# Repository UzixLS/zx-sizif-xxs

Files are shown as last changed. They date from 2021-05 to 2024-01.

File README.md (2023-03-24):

## Sizif-XXS
Smallest FPGA-based ZX Spectrum clone with real Z80.

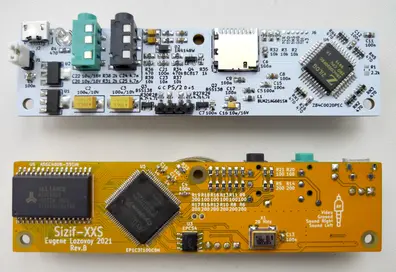
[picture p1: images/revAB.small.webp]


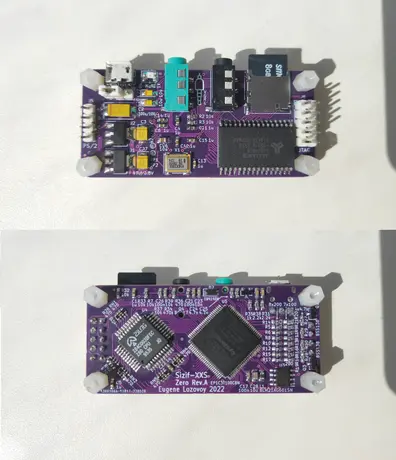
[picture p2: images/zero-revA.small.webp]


### Tech specs
* Two PCB varians: 100x24.5mm (main version) and 65x30mm (Zero version) - both are functionally identical, differs only in size
* PS/2 keyboard
* Pentagon, Spectrum 128, Spectrum 48 and Spectrum +3e modes
* Altera EP1C3T100 FPGA
* Real Z80 with 3.5MHz, 4.4MHz, 5.2MHz, 7MHz (no-wait turbo) and 14MHz (turbo with wait-states) modes
* 512K RAM
* TurboSound with switchable stereo ABC/ACB/mono output
* Integrated DivMMC and Z-Controller, 1x microSD socket
* PAL video output (AV cable like in Raspberry Pi)
* ULAplus
* SpecDrum
* Covox (Pentagon standard - port #FD)
* SounDrive (4-channel stereo covox - ports #0F, #1F, #4F, #5F)
* Tape input via 3.5" jack
* USB 5V power supply

### Magic button
Sizif has a number of configurable parameters that you can change on the fly. To do this just hold Magic button for a second.

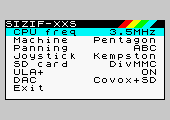
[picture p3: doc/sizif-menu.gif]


To navigate menu you can use up-down keys, to change value use enter or left-right keys. Kempston, Sinclair, Cursor and QAOP supported.

If you press Magic button for a short time, the standard NMI handler 'll be called.

### PS/2 keyboard buttons
| Button | Function |
| - | - |
| F1 | Pause |
| F5 | Magic button |
| F10 | Reboot |
| F12 | Reboot |
| Ctrl+Alt+Del | Reboot |
| Ctrl+Alt+Backspace | Reboot |
| Numpad 8, 2/5, 4, 6 | Joystick's up-down-left-right |
| Numpad 0/Enter | Joystick's fire |
| Alt | Joystick's fire |

### RAM
Sizif contains 512K RAM. 128K available via 7FFDh port, 128K via DFFDh (Profi standart, most compatible with old 128K software) and 128K used for DivMMC. Remaining space used to store ROM. Note that DFFDh port available only in Pentagon mode.

### SD card
Sizif have preinstalled esxDOS firmware, which provides ability to load TAP, TRD, SCL, Z80 files and save snapshots. To use this you should format SD cart to FAT32 or FAT16 and unpack latest esxDOS release ([link](http://www.esxdos.org/index.html)) to card. Also it's recommended to install Long Filename Browser ([link](https://spectrumcomputing.co.uk/forums/viewtopic.php?t=2553)) to card.

### How to program
There is two options:
1. Program via JTAG connector using USB blaster and Quartus Programmer - use jic file from out folder.
2. Program flash chip directly using TL866 or similar device - use bin file.

### Changelog & current status
* Rev.A - first release. Please note the [errata](pcb/rev.A/ERRATA.txt).
* Rev.B:
    * fixed all rev.A issues
    * fixed "jailbars" on video output
    * 0805 footprints replaced with 0603
    * tape input moved slightly away to not to interfere with wide AV jack
    * 3.5 jacks replaced with THT variant for better reliability
    * changed ps/2 header orientation
* Zero Rev.A - first release of Zero version. Based on Rev.B of main pcb.

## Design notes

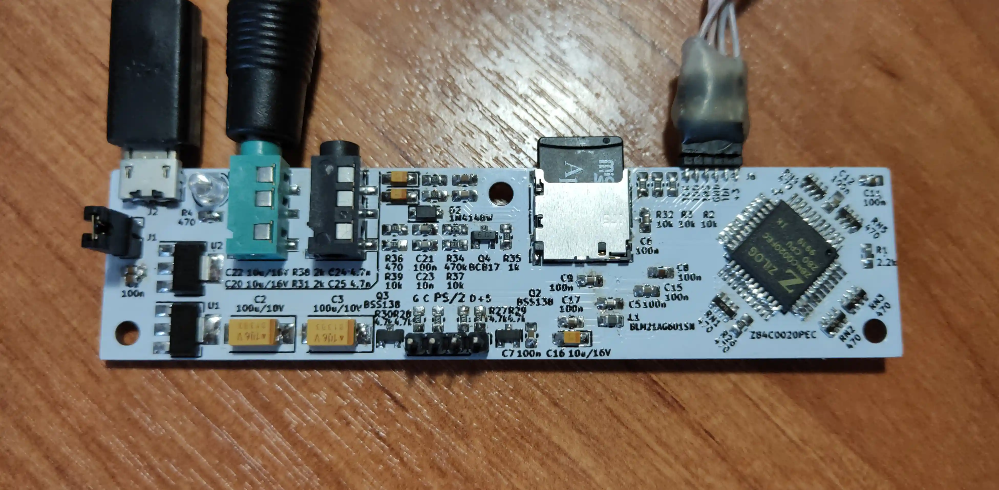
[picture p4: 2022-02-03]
images/revA.webp

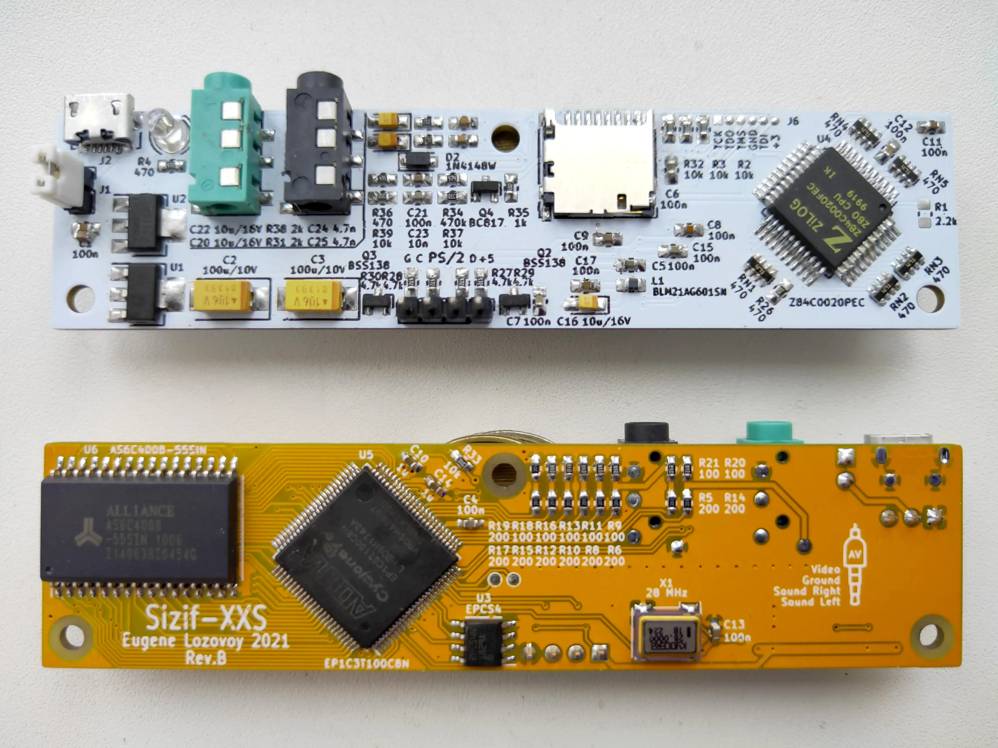
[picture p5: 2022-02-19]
images/revAB.webp

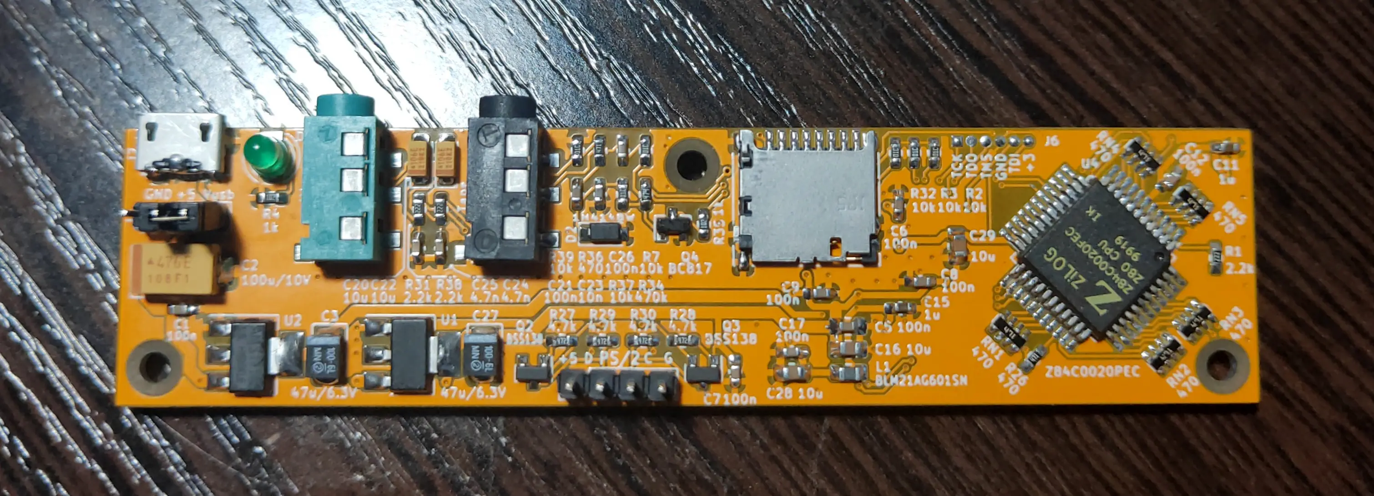
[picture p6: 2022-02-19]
images/revB.webp

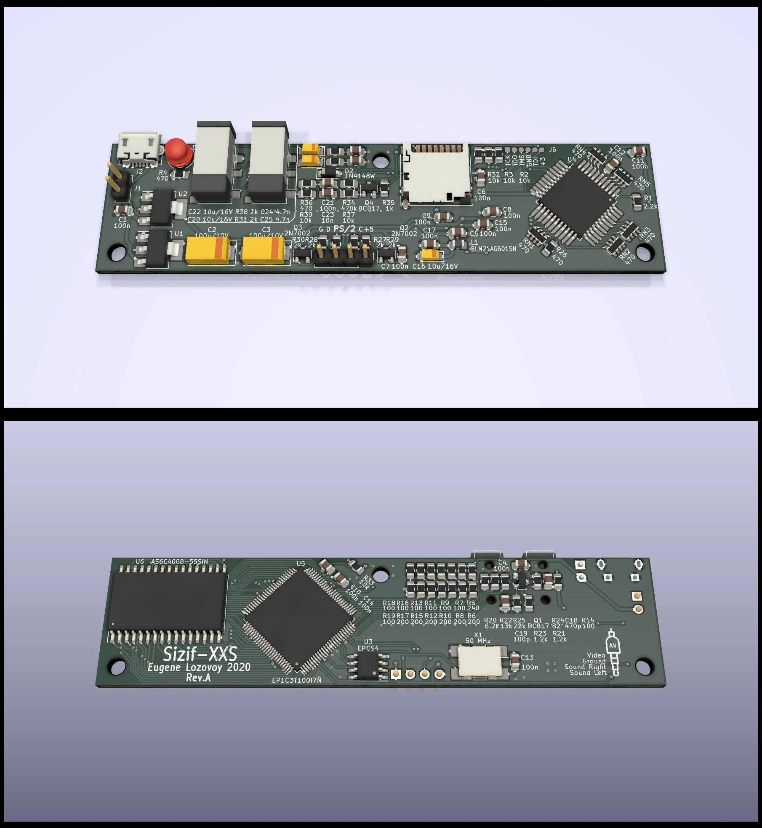
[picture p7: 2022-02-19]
out/pcb3d.rev.A.webp

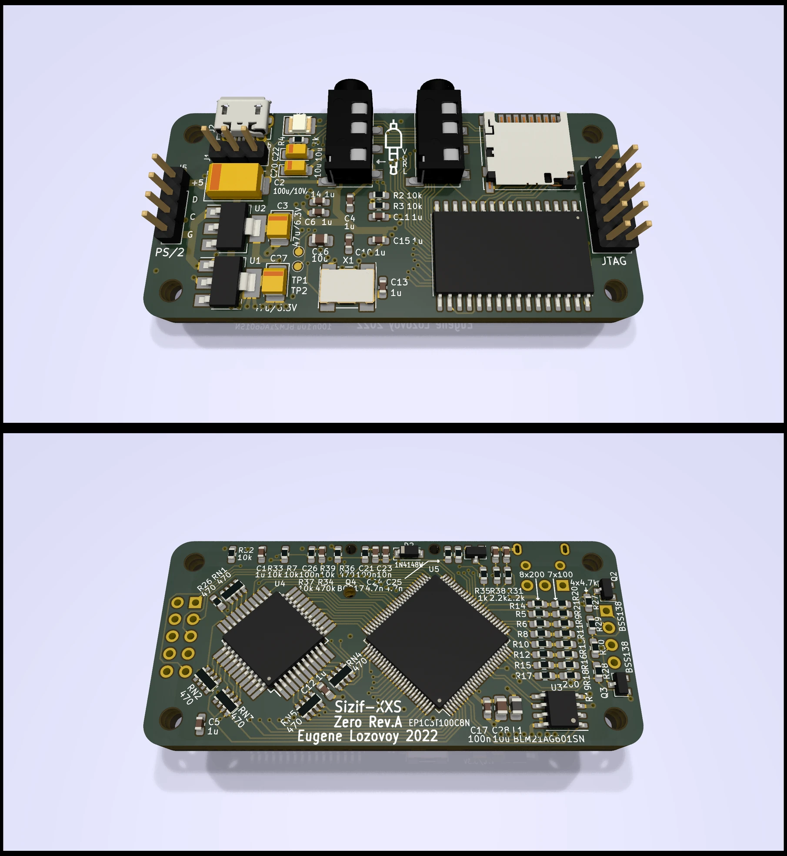
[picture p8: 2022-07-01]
out/pcb3d.zero.rev.A.webp

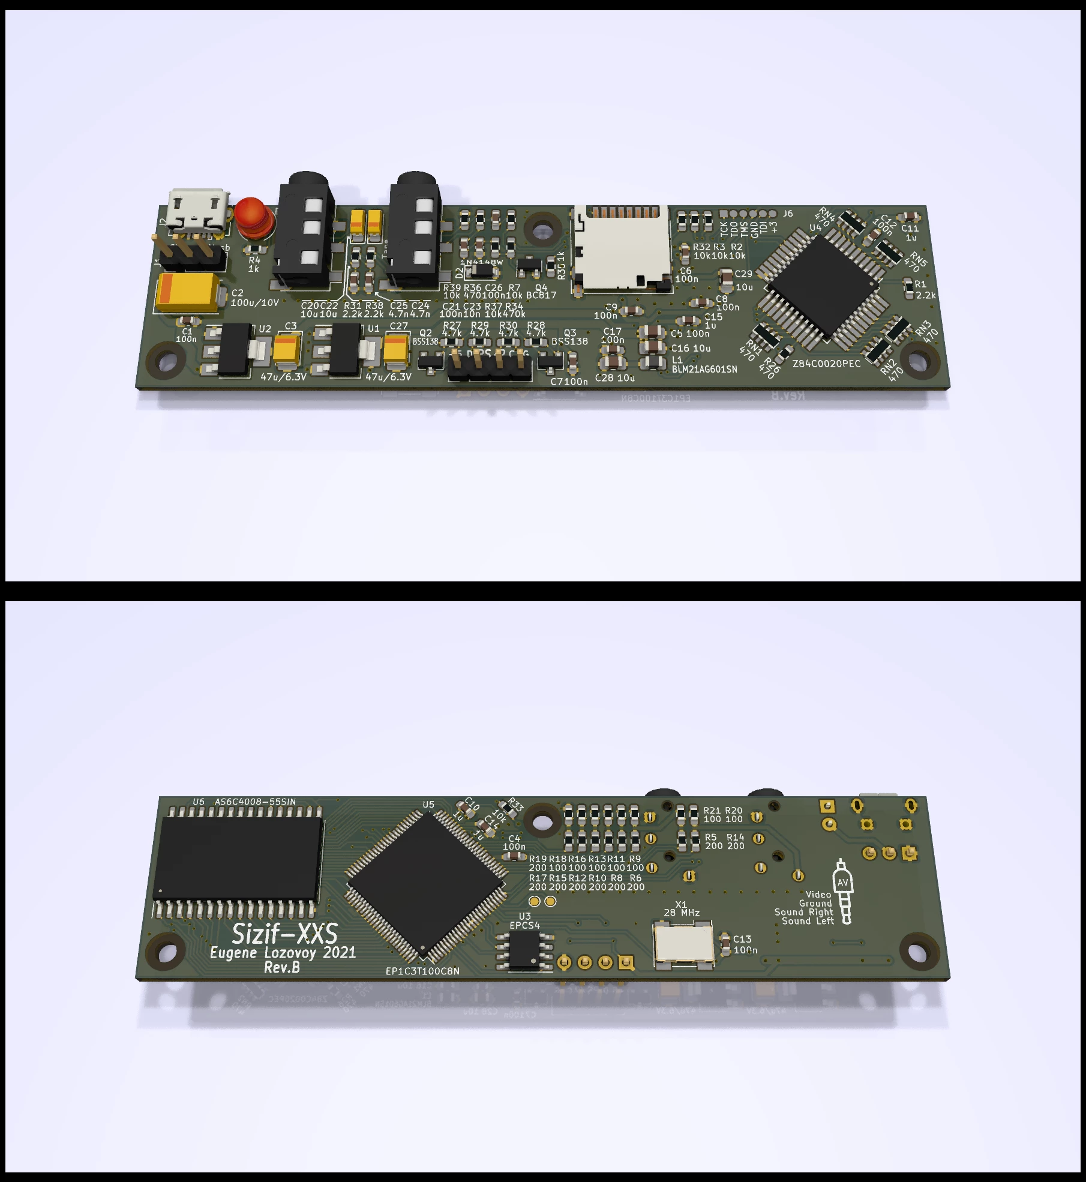
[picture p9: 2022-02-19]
out/pcb3d.rev.B.webp

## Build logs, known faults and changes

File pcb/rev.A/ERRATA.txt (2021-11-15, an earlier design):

- X1 - 28MHz
- R5 should be 200
- R14 should be 0
- R19 should be 200
- do not install: R20, R21, R22, R23, R24, R25, C18, C19, Q1

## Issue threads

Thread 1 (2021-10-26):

Composite video signal issue

cpufun, 2021-10-26:
Присутствует проблема с композитным видеосигналом. Не удается добиться устойчивого изображения. Картинка срывается постоянно, на одном экране видно четыре изображения, вместо одного, всё изображение - черно-белое.

Closed 2021-11-01.

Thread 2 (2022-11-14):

ZX-sizif-xxs

digits1, 2022-11-14:
Евгений добрый вечер! Очень понравился ваш  проект. Очень хочу повторить. Возник вопрос такого характера. Можно ли применить процессор Z84C0010FEC вместо Z84C0020FEC? Спасибо, с уважением!

UzixLS, 2022-11-15:
Я пробовал на плате Zero - работает.

SCybore, 2022-12-21:
Приветствую, Евгений! Можно ли приобрести готовую плату Zero?

UzixLS, 2022-12-22:
> Приветствую, Евгений! Можно ли приобрести готовую плату Zero?

Можно, например, тут: https://www.pcbway.com/project/shareproject/Sizif_XXS_Zero_rev_A_83378be5.html

Closed 2023-04-20.

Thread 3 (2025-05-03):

I CANNOT WRITE TO EPCS4 MEMORY

nicolaebizi, 2025-05-03:
HELLO!
I can't write the epcs4 memory, maybe I'm not doing something right.
I also tried with XGECU PRO TL48, which reports ff ff ff on the ID.
I bought 5 pieces and all the same.

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

UzixLS, 2025-05-04:
Fake or dead ICs probably

nicolaebizi, 2025-05-04:
> Fake or dead ICs probably

Tanks !

nicolaebizi, 2025-05-08:
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
to day put 25vf040b and start

nicolaebizi, 2025-05-09:
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
Tanks for project

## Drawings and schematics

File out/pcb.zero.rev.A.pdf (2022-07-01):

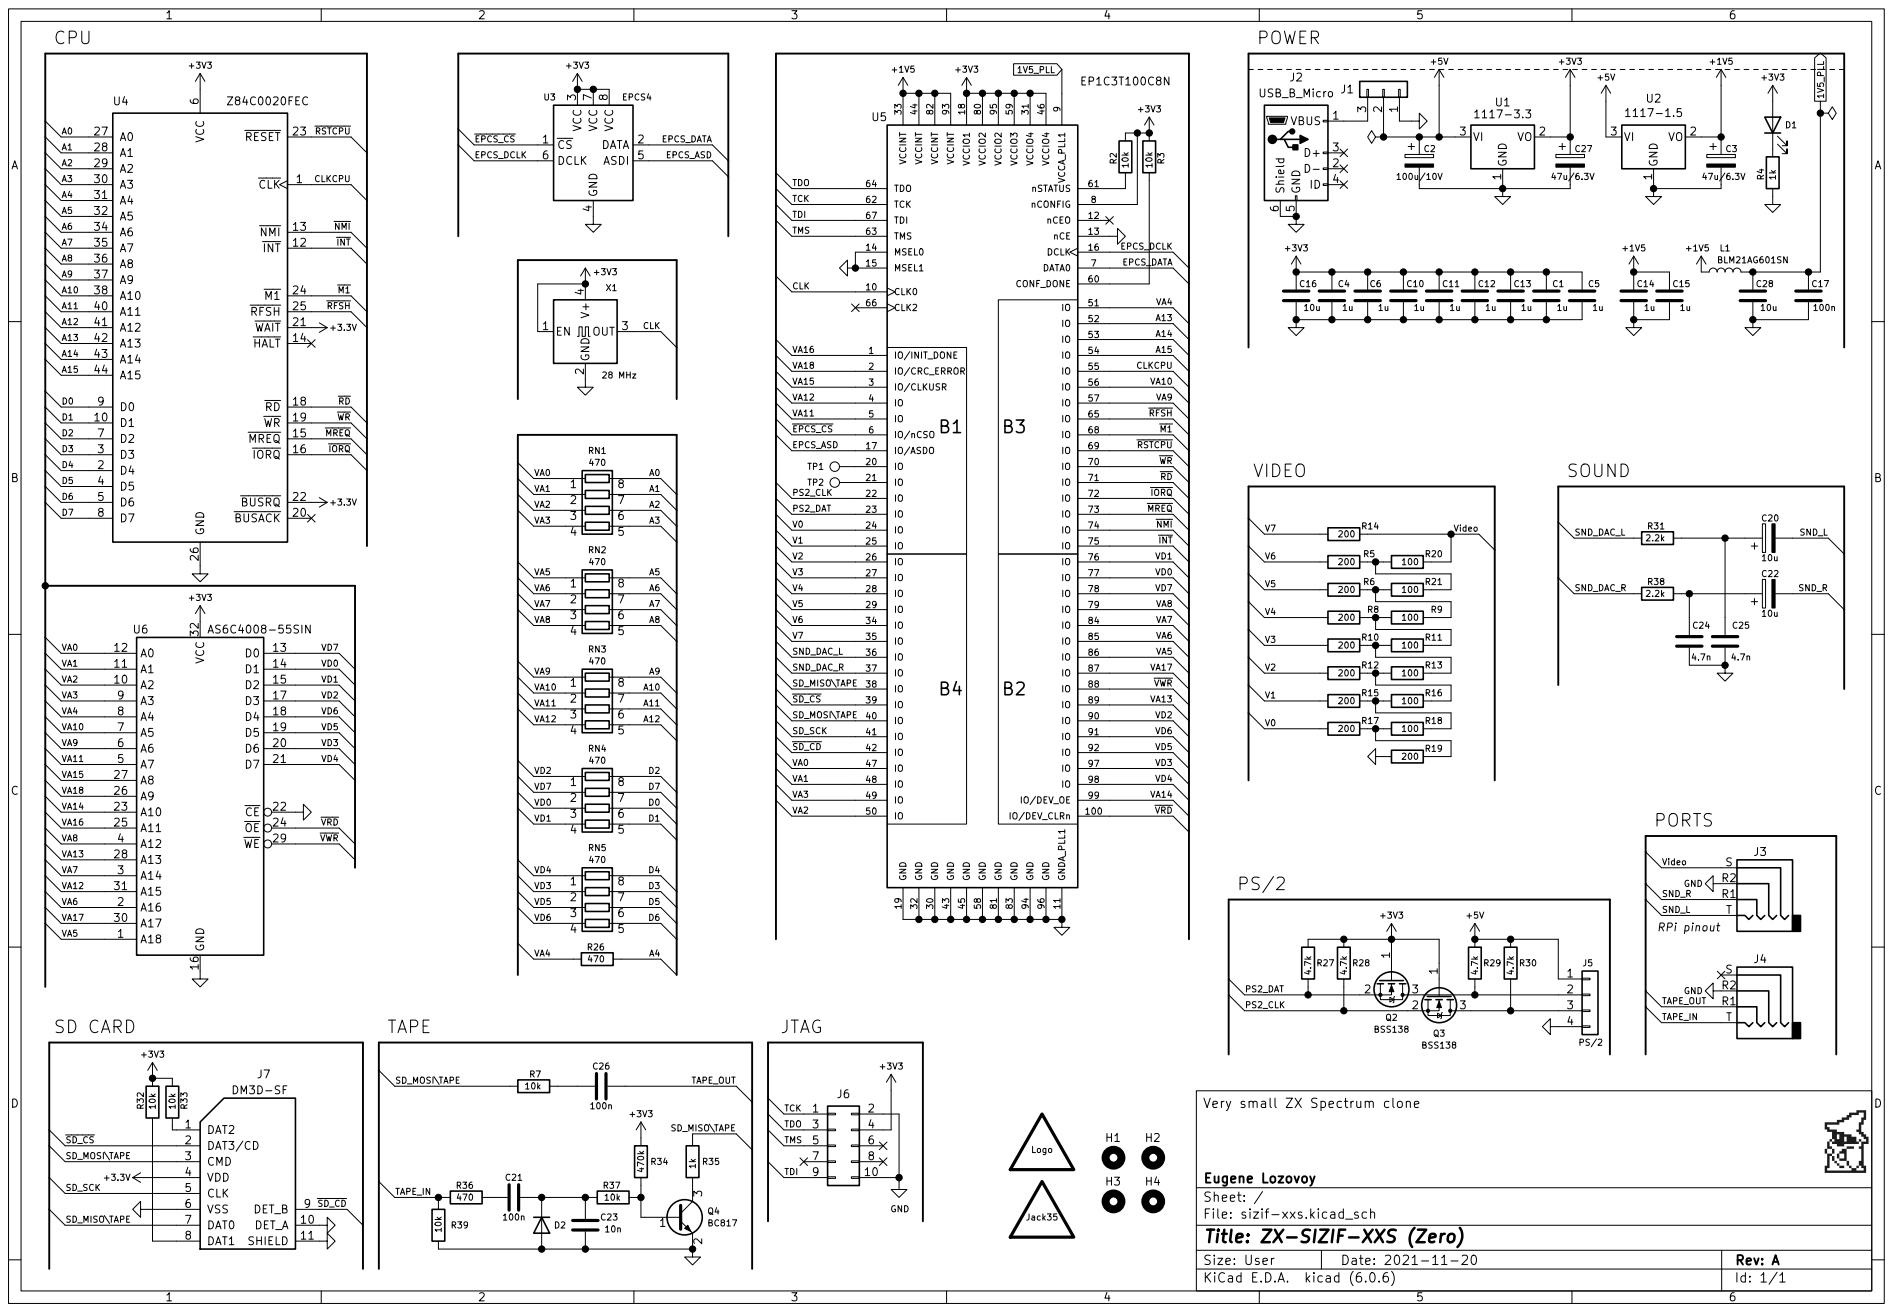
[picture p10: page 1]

~{WR} | VA11 | IO 5
~{MREQ} | | IO/nCSO 6

Very small ZX Spectrum clone

Eugene Lozovoy
Sheet: /
File: sizif-xxs.kicad_sch
Title: ZX-SIZIF-XXS (Zero)

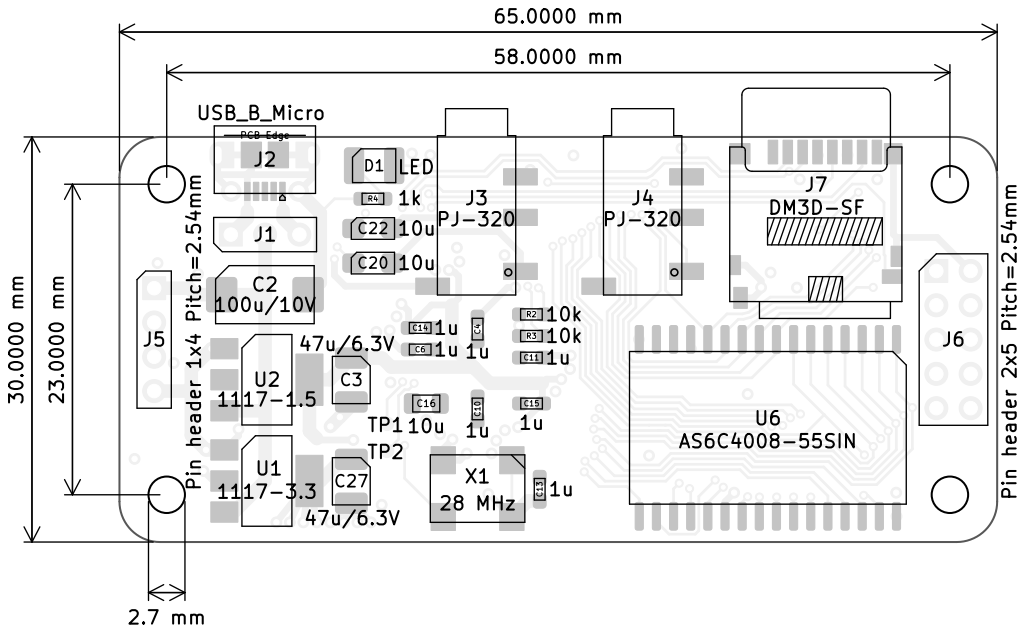
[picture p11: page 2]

J3 | | J4 | DM3D-SF
PJ-320

Eugene Lozovoy
Sheet: Assembly
File: sizif-xxs.kicad_pcb
Title: ZX-SIZIF-XXS (Zero)

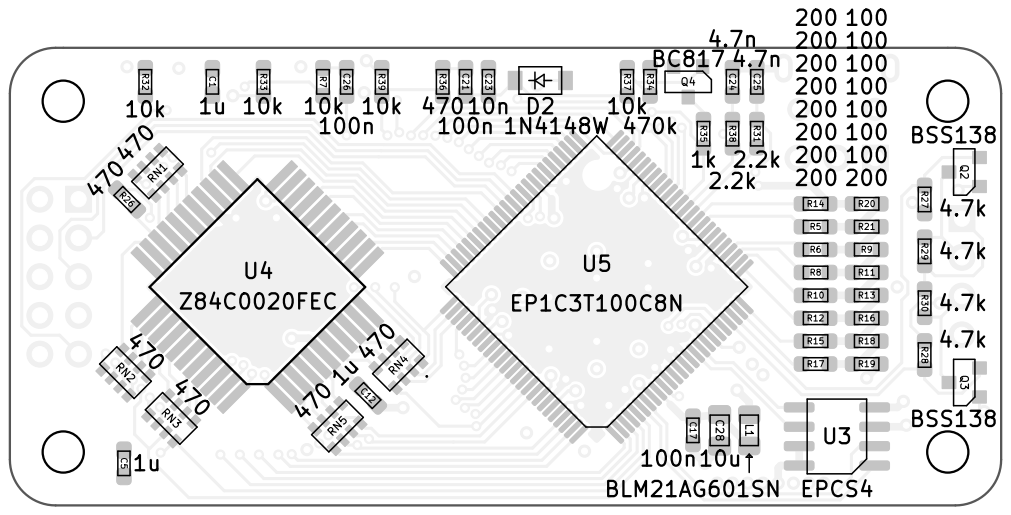
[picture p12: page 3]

Eugene Lozovoy
Sheet: Assembly
File: sizif-xxs.kicad_pcb
Title: ZX-SIZIF-XXS (Zero)

Designator | Package | Value | Quantity
C1, C4, C5, C6, C10, C11, C12, C13, C14, C15 | C_0603_1608Metric_Pad1.08x0.95mm_HandSolder | 1u | 10
C2 | CP_EIA-7343-31_Kemet-D_Pad2.25x2.55mm_HandSolder | 100u/10V | 1
C3, C27 | CP_EIA-3528-21_Kemet-B_Pad1.50x2.35mm_HandSolder | 47u/6.3V | 2
C16, C28 | C_0805_2012Metric_Pad1.18x1.45mm_HandSolder | 10u | 2
C17, C21, C26 | C_0603_1608Metric_Pad1.08x0.95mm_HandSolder | 100n | 3
C20, C22 | CP_EIA-3216-18_Kemet-A_Pad1.58x1.35mm_HandSolder | 10u | 2
C23 | C_0603_1608Metric_Pad1.08x0.95mm_HandSolder | 10n | 1
C24, C25 | C_0603_1608Metric_Pad1.08x0.95mm_HandSolder | 4.7n | 2
D1 | LED_1210_3225Metric_Pad1.42x2.65mm_HandSolder | LED | 1
D2 | D_SOD-123 | 1N4148W | 1
J1 | PinHeader_1x03_P2.54mm_Vertical | Pin header 1x3 Pitch=2.54mm | 1
J2 | USB_Micro-B_Molex-105017-0001 | USB_B_Micro | 1
J3, J4 | Jack_3.5mm_PJ320D_Horizontal | PJ-320 | 2
J5 | PinHeader_1x04_P2.54mm_Vertical | Pin header 1x4 Pitch=2.54mm | 1
J6 | PinHeader_2x05_P2.54mm_Vertical | Pin header 2x5 Pitch=2.54mm | 1
J7 | microSD_HC_Hirose_DM3D-SF | DM3D-SF | 1
L1 | L_0805_2012Metric_Pad1.15x1.40mm_HandSolder | BLM21AG601SN | 1
Q2, Q3 | SOT-23 | BSS138 | 2
Q4 | SOT-23 | BC817 | 1
R2, R3, R7, R32, R33, R37, R39 | R_0603_1608Metric_Pad0.98x0.95mm_HandSolder | 10k | 7
R4, R35 | R_0603_1608Metric_Pad0.98x0.95mm_HandSolder | 1k | 2
R5, R6, R8, R10, R12, R14, R15, R17, R19 | R_0603_1608Metric_Pad0.98x0.95mm_HandSolder | 200 | 9
R9, R11, R13, R16, R18, R20, R21 | R_0603_1608Metric_Pad0.98x0.95mm_HandSolder | 100 | 7
R26, R36 | R_0603_1608Metric_Pad0.98x0.95mm_HandSolder | 470 | 2
R27, R28, R29, R30 | R_0603_1608Metric_Pad0.98x0.95mm_HandSolder | 4.7k | 4
R31, R38 | R_0603_1608Metric_Pad0.98x0.95mm_HandSolder | 2.2k | 2
R34 | R_0603_1608Metric_Pad0.98x0.95mm_HandSolder | 470k | 1
RN1, RN2, RN3, RN4, RN5 | R_Array_Convex_4x0603 | 470 | 5
U1 | SOT-223-3_TabPin2 | 1117-3.3 | 1
U2 | SOT-223-3_TabPin2 | 1117-1.5 | 1
U3 | SOIC-8_3.9x4.9mm_P1.27mm | EPCS4 | 1
U4 | TQFP-44_14x14mm_P0.8mm | Z84C0020FEC | 1
U5 | TQFP-100_14x14mm_P0.5mm | EP1C3T100C8N | 1
U6 | SSOP-32_11.305x20.495mm_P1.27mm | AS6C4008-55SIN | 1
X1 | Oscillator_SMD_SeikoEpson_SG8002CA-4Pin_7.0x5.0mm | 28 MHz | 1

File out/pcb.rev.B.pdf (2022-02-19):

1 | 2 | 3 | 4 | 5 | 6

A

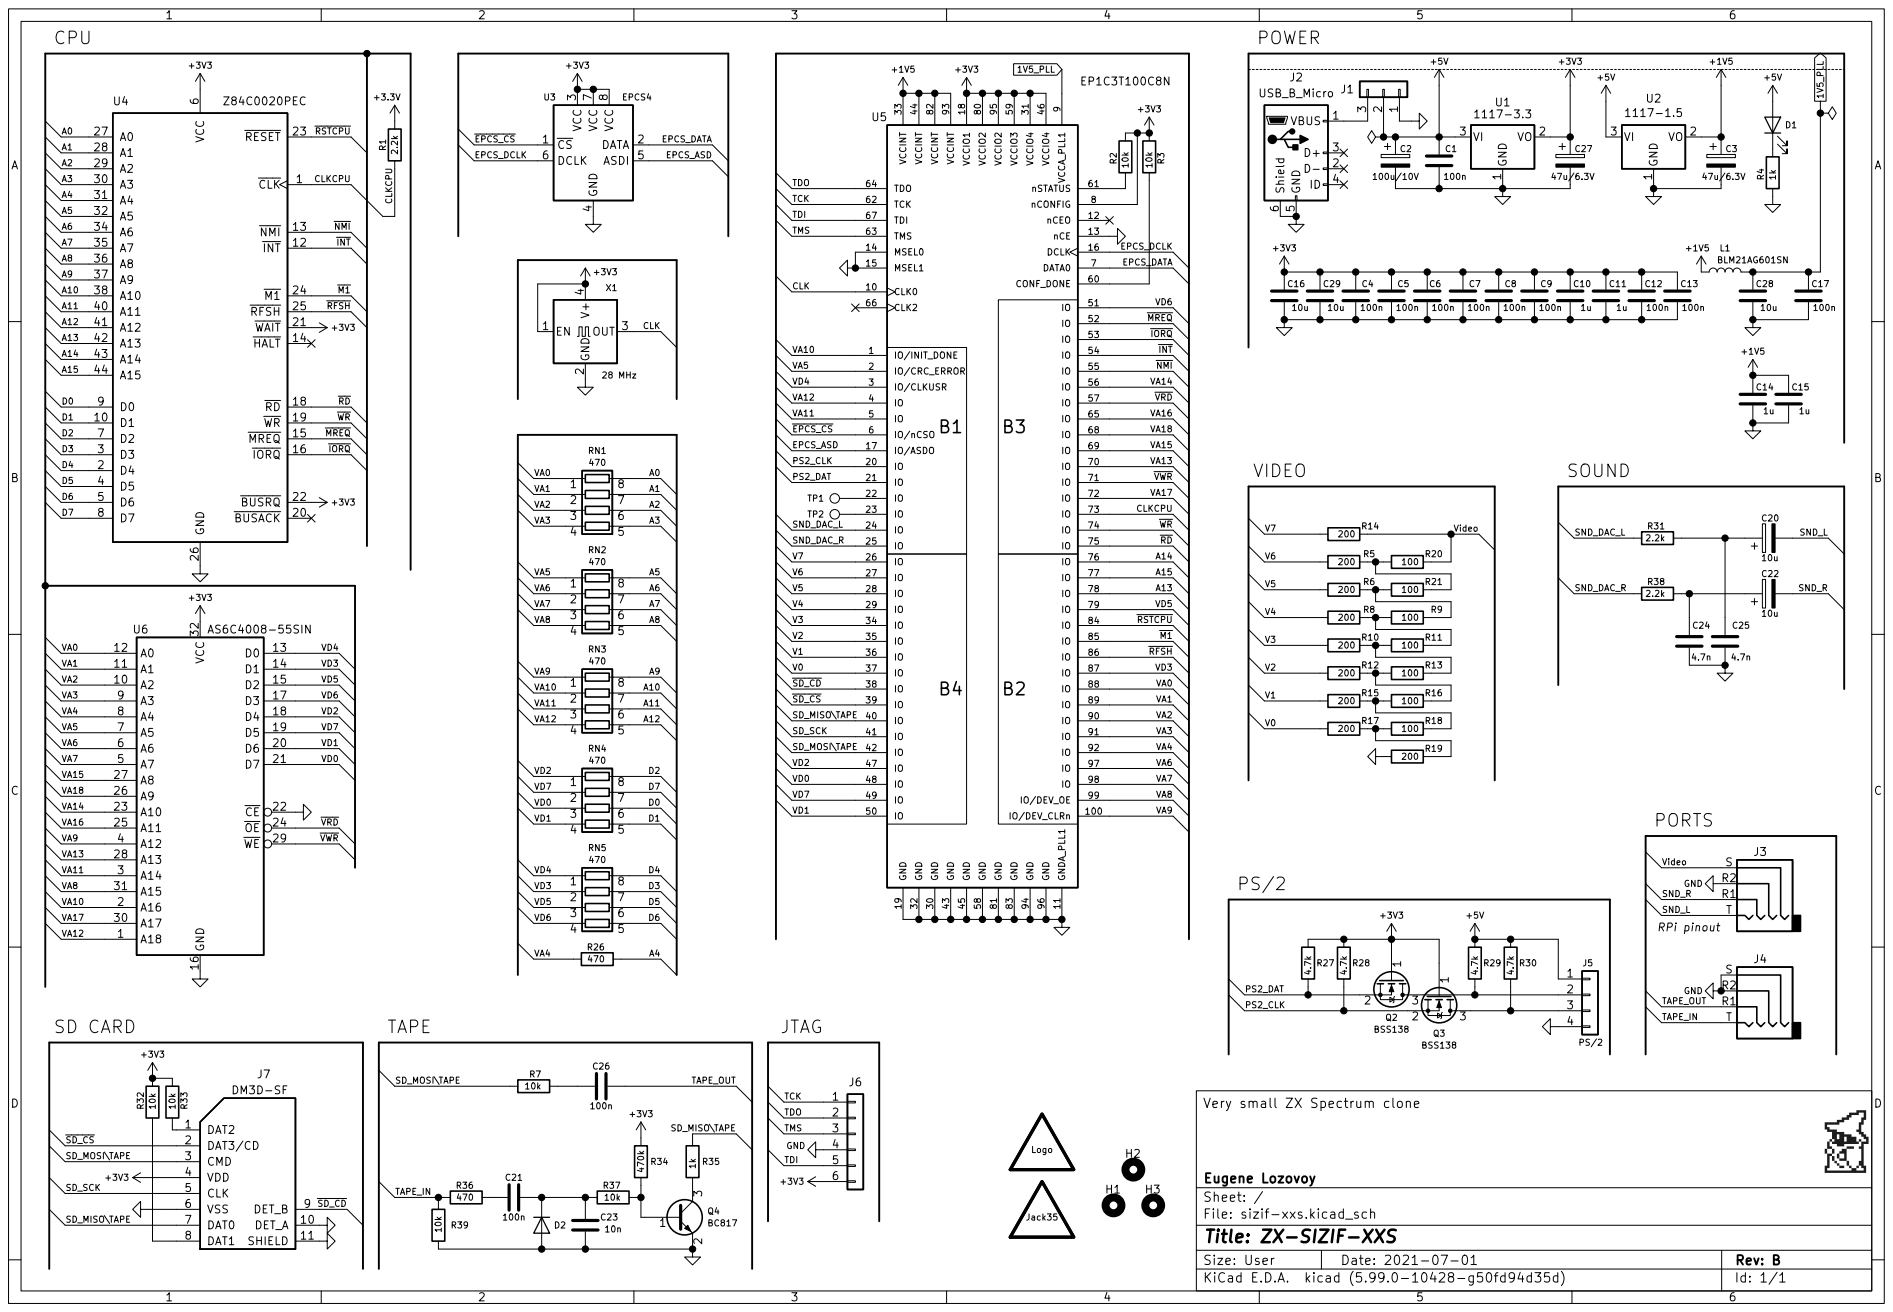
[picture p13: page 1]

Very small ZX Spectrum clone

Eugene Lozovoy
Sheet: /
File: sizif-xxs.kicad_sch
Title: ZX-SIZIF-XXS

A

A

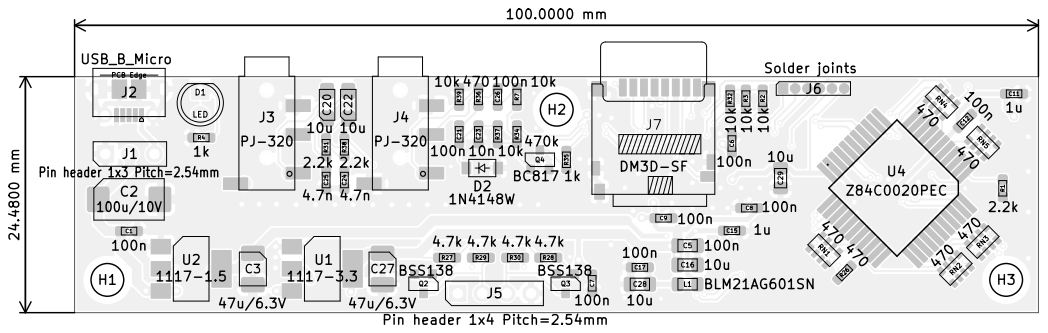
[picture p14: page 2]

PCB Edge | J3 PJ-320 | J4 PJ-320 | 10k H2 | J6

Sheet: Assembly
File: sizif-xxs.kicad_pcb
Title: ZX Sizif-XXS

A

A

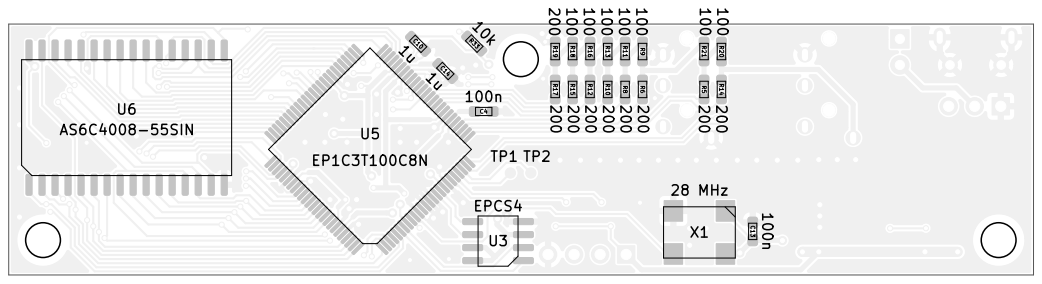
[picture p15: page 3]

Sheet: Assembly
File: sizif-xxs.kicad_pcb
Title: ZX Sizif-XXS

References | Value | Footprint | Quantity
C1, C4, C6, C7, C8, C9, C12, C13, C17, C21, C26 | 100n | C_0603_1608Metric_Pad1.08x0.95mm_HandSolder | 11
C2 | 100u/10V | CP_EIA-7343-31_Kemet-D_Pad2.25x2.55mm_HandSolder | 1
C3, C27 | 47u/6.3V | CP_EIA-3528-21_Kemet-B_Pad1.50x2.35mm_HandSolder | 2
C5 | 100n | C_0805_2012Metric_Pad1.18x1.45mm_HandSolder | 1
C10, C11, C14, C15 | 1u | C_0603_1608Metric_Pad1.08x0.95mm_HandSolder | 4
C16, C28, C29 | 10u | C_0805_2012Metric_Pad1.18x1.45mm_HandSolder | 3
C20, C22 | 10u | CP_EIA-3216-18_Kemet-A_Pad1.58x1.35mm_HandSolder | 2
C23 | 10n | C_0603_1608Metric_Pad1.08x0.95mm_HandSolder | 1
C24, C25 | 4.7n | C_0603_1608Metric_Pad1.08x0.95mm_HandSolder | 2
D1 | LED | LED_D4.0mm | 1
D2 | 1N4148W | D_SOD-123 | 1
J1 | Pin header 1x3 Pitch=2.54mm | PinHeader_1x03_P2.54mm_Vertical | 1
J2 | USB_B_Micro | USB_Micro-B_Molex-105017-0001 | 1
J3, J4 | PJ-320 | PJ-320A_D | 2
J5 | Pin header 1x4 Pitch=2.54mm | PinHeader_1x04_P2.54mm_Vertical | 1
J7 | DM3D-SF | microSD_HC_Hirose_DM3D-SF | 1
L1 | BLM21AG601SN | L_0805_2012Metric_Pad1.15x1.40mm_HandSolder | 1
Q2, Q3 | BSS138 | SOT-23 | 2
Q4 | BC817 | SOT-23 | 1
R1, R31, R38 | 2.2k | R_0603_1608Metric_Pad0.98x0.95mm_HandSolder | 3
R2, R3, R7, R32, R33, R37, R39 | 10k | R_0603_1608Metric_Pad0.98x0.95mm_HandSolder | 7
R4, R35 | 1k | R_0603_1608Metric_Pad0.98x0.95mm_HandSolder | 2
R5, R6, R8, R10, R12, R14, R15, R17, R19 | 200 | R_0603_1608Metric_Pad0.98x0.95mm_HandSolder | 9
R9, R11, R13, R16, R18, R20, R21 | 100 | R_0603_1608Metric_Pad0.98x0.95mm_HandSolder | 7
R26, R36 | 470 | R_0603_1608Metric_Pad0.98x0.95mm_HandSolder | 2
R27, R28, R29, R30 | 4.7k | R_0603_1608Metric_Pad0.98x0.95mm_HandSolder | 4
R34 | 470k | R_0603_1608Metric_Pad0.98x0.95mm_HandSolder | 1
RN1, RN2, RN3, RN4, RN5 | 470 | R_Array_Convex_4x0603 | 5
U1 | 1117-3.3 | SOT-223-3_TabPin2 | 1
U2 | 1117-1.5 | SOT-223-3_TabPin2 | 1
U3 | EPCS4 | SOIC-8_3.9x4.9mm_P1.27mm | 1
U4 | Z84C0020PEC | TQFP-44_14x14mm_P0.8mm | 1
U5 | EP1C3T100C8N | TQFP-100_14x14mm_P0.5mm | 1
U6 | AS6C4008-55SIN | SSOP-32_11.305x20.495mm_P1.27mm | 1
X1 | 28 MHz | Oscillator_SMD_SeikoEpson_SG8002CA-4Pin_7.0x5.0mm | 1

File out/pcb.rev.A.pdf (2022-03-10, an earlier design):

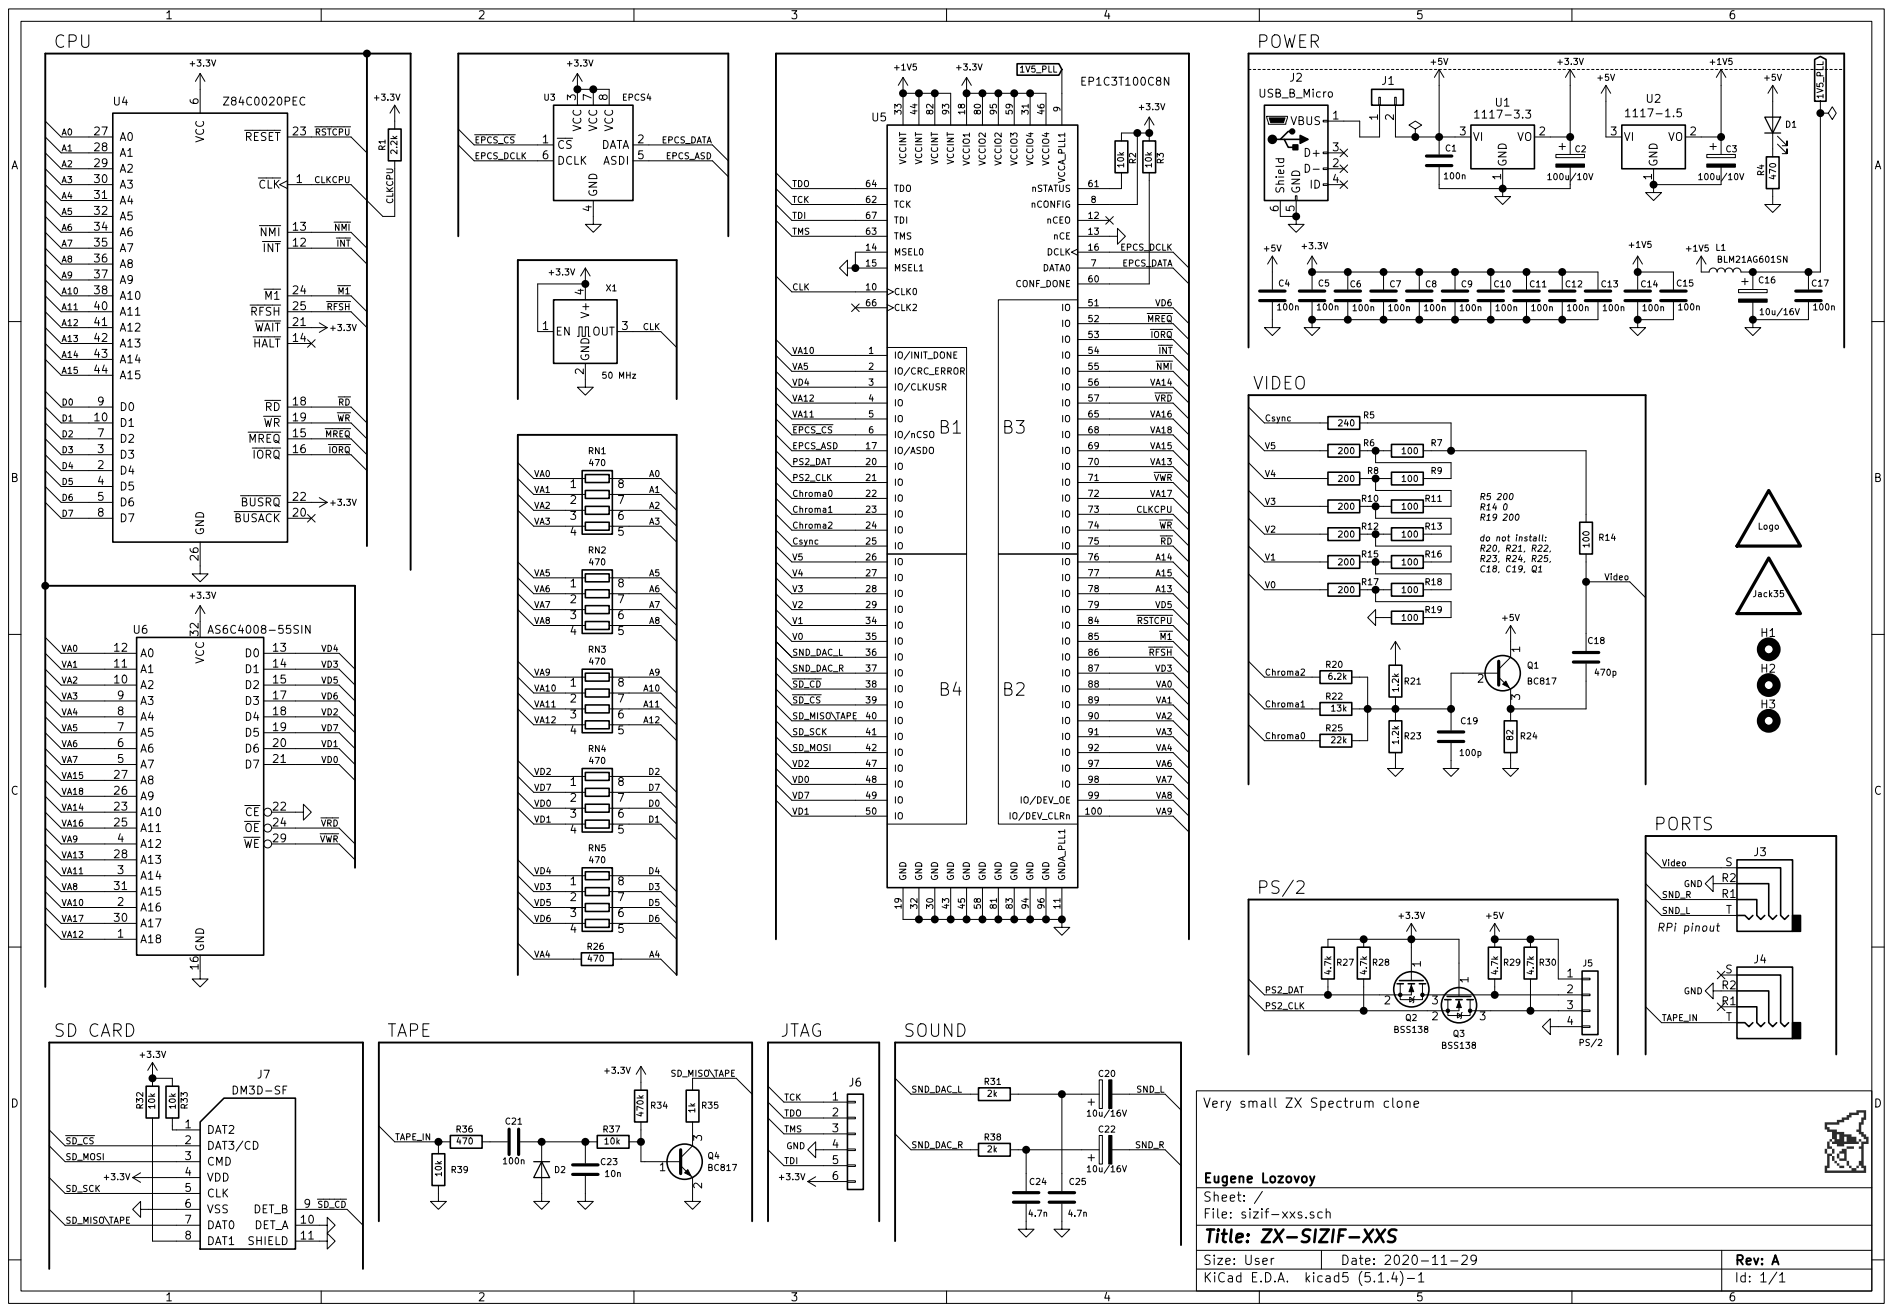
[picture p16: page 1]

Csync

Very small ZX Spectrum clone

Sheet: /

File: sizif-xxs.sch

Title: ZX-SIZIF-XXS

Size: User | Date: 2020-11-29 | Rev: A

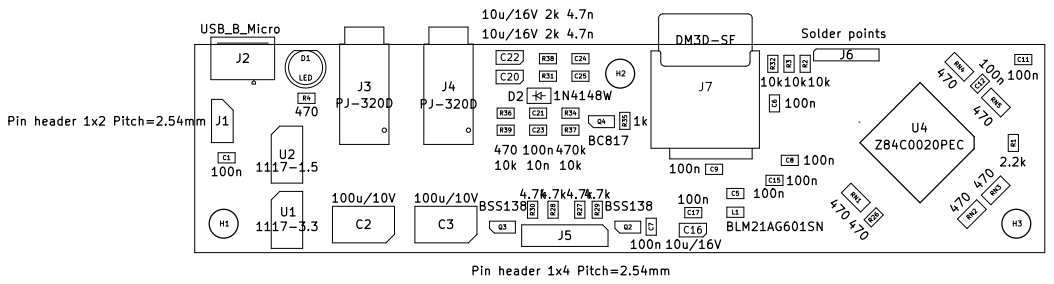
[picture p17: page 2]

Sheet:

Title: ZX Sizif-XXS

Size: A4 | Date: 2020-05-05 | Rev: A

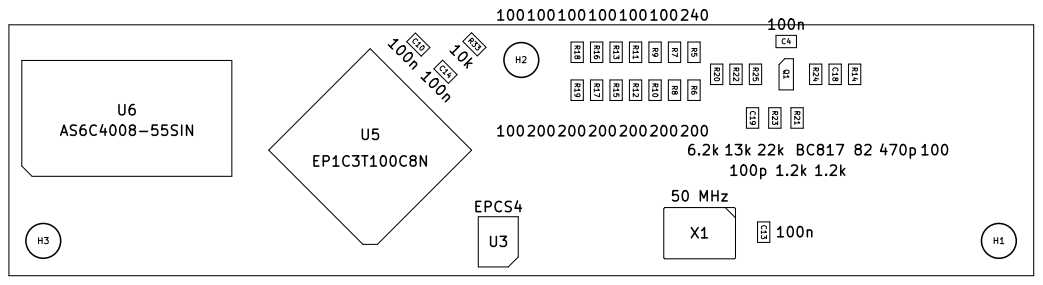
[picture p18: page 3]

Sheet:

Title: ZX Sizif-XXS

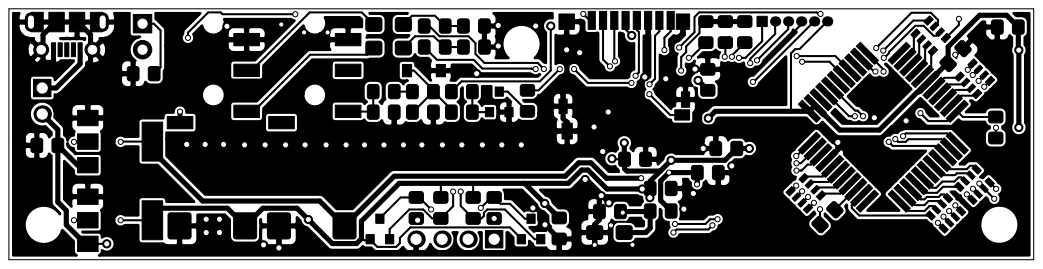
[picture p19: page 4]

Sheet:

Title: ZX Sizif-XXS

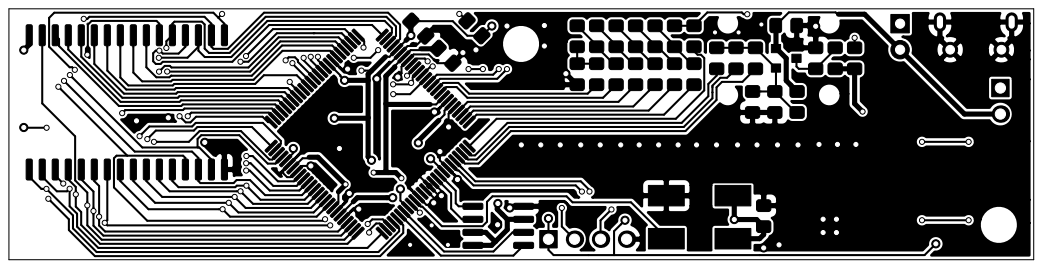
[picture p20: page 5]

Sheet:

Title: ZX Sizif-XXS

References | Value | Footprint | Quantity
C16, C20, C22 | 10u/16V | CP_EIA-3216-18_Kemet-A_Pad1.58x1.35mm_HandSolder | 3
C2, C3 | 100u/10V | CP_EIA-7343-31_Kemet-D_Pad2.25x2.55mm_HandSolder | 2
C1, C4, C5, C6, C7, C8, C9, C10, C11, C12, C13, C14, C15, C17, C21 | 100n | C_0805_2012Metric_Pad1.15x1.40mm_HandSolder | 15
C24, C25 | 4.7n | C_0805_2012Metric_Pad1.15x1.40mm_HandSolder | 2
C18 | 470p | C_0805_2012Metric_Pad1.15x1.40mm_HandSolder | 1
C19 | 100p | C_0805_2012Metric_Pad1.15x1.40mm_HandSolder | 1
C23 | 10n | C_0805_2012Metric_Pad1.15x1.40mm_HandSolder | 1
R7, R9, R11, R13, R14, R16, R18, R19 | 100 | R_0805_2012Metric_Pad1.15x1.40mm_HandSolder | 8
R2, R3, R32, R33, R37, R39 | 10k | R_0805_2012Metric_Pad1.15x1.40mm_HandSolder | 6
R6, R8, R10, R12, R15, R17 | 200 | R_0805_2012Metric_Pad1.15x1.40mm_HandSolder | 6
R27, R28, R29, R30 | 4.7k | R_0805_2012Metric_Pad1.15x1.40mm_HandSolder | 4
R4, R26, R36 | 470 | R_0805_2012Metric_Pad1.15x1.40mm_HandSolder | 3
R21, R23 | 1.2k | R_0805_2012Metric_Pad1.15x1.40mm_HandSolder | 2
R31, R38 | 2k | R_0805_2012Metric_Pad1.15x1.40mm_HandSolder | 2
R1 | 2.2k | R_0805_2012Metric_Pad1.15x1.40mm_HandSolder | 1
R5 | 240 | R_0805_2012Metric_Pad1.15x1.40mm_HandSolder | 1
R20 | 6.2k | R_0805_2012Metric_Pad1.15x1.40mm_HandSolder | 1
R22 | 13k | R_0805_2012Metric_Pad1.15x1.40mm_HandSolder | 1
R24 | 82 | R_0805_2012Metric_Pad1.15x1.40mm_HandSolder | 1
R25 | 22k | R_0805_2012Metric_Pad1.15x1.40mm_HandSolder | 1
R34 | 470k | R_0805_2012Metric_Pad1.15x1.40mm_HandSolder | 1
R35 | 1k | R_0805_2012Metric_Pad1.15x1.40mm_HandSolder | 1
L1 | BLM21AG601SN | L_0805_2012Metric_Pad1.15x1.40mm_HandSolder | 1
D2 | 1N4148W | D_SOD-123 | 1
D1 | LED | LED_D4.0mm | 1
U3 | EPCS4 | SOIC-8_3.9x4.9mm_P1.27mm | 1
U1 | 1117-3.3 | SOT-223-3_TabPin2 | 1
U2 | 1117-1.5 | SOT-223-3_TabPin2 | 1
U6 | AS6C4008-55SIN | SSOP-32_11.305x20.495mm_P1.27mm | 1
U5 | EP1C3T100C8N | TQFP-100_14x14mm_P0.5mm | 1
U4 | Z84C0020PEC | TQFP-44_14x14mm_P0.8mm | 1
X1 | 50 MHz | Oscillator_SMD_EuroQuartz_XO91-4Pin_7.0x5.0mm_HandSoldering | 1
RN1, RN2, RN3, RN4, RN5 | 470 | R_Array_Convex_4x0603 | 5
Q1, Q4 | BC817 | SOT-23 | 2
Q2, Q3 | BSS138 | SOT-23 | 2
J3, J4 | PJ-320D | Jack_3.5mm_PJ320D_Horizontal | 2
J5 | Pin header 1x4 Pitch=2.54mm | PinHeader_1x04_P2.54mm_Vertical | 1
J1 | Pin header 1x2 Pitch=2.54mm | PinHeader_2x01_P2.54mm_Vertical | 1
J2 | USB_B_Micro | USB_Micro-B_Molex-105017-0001 | 1
J7 | DM3D-SF | microSD_HC_Hirose_DM3D-SF | 1

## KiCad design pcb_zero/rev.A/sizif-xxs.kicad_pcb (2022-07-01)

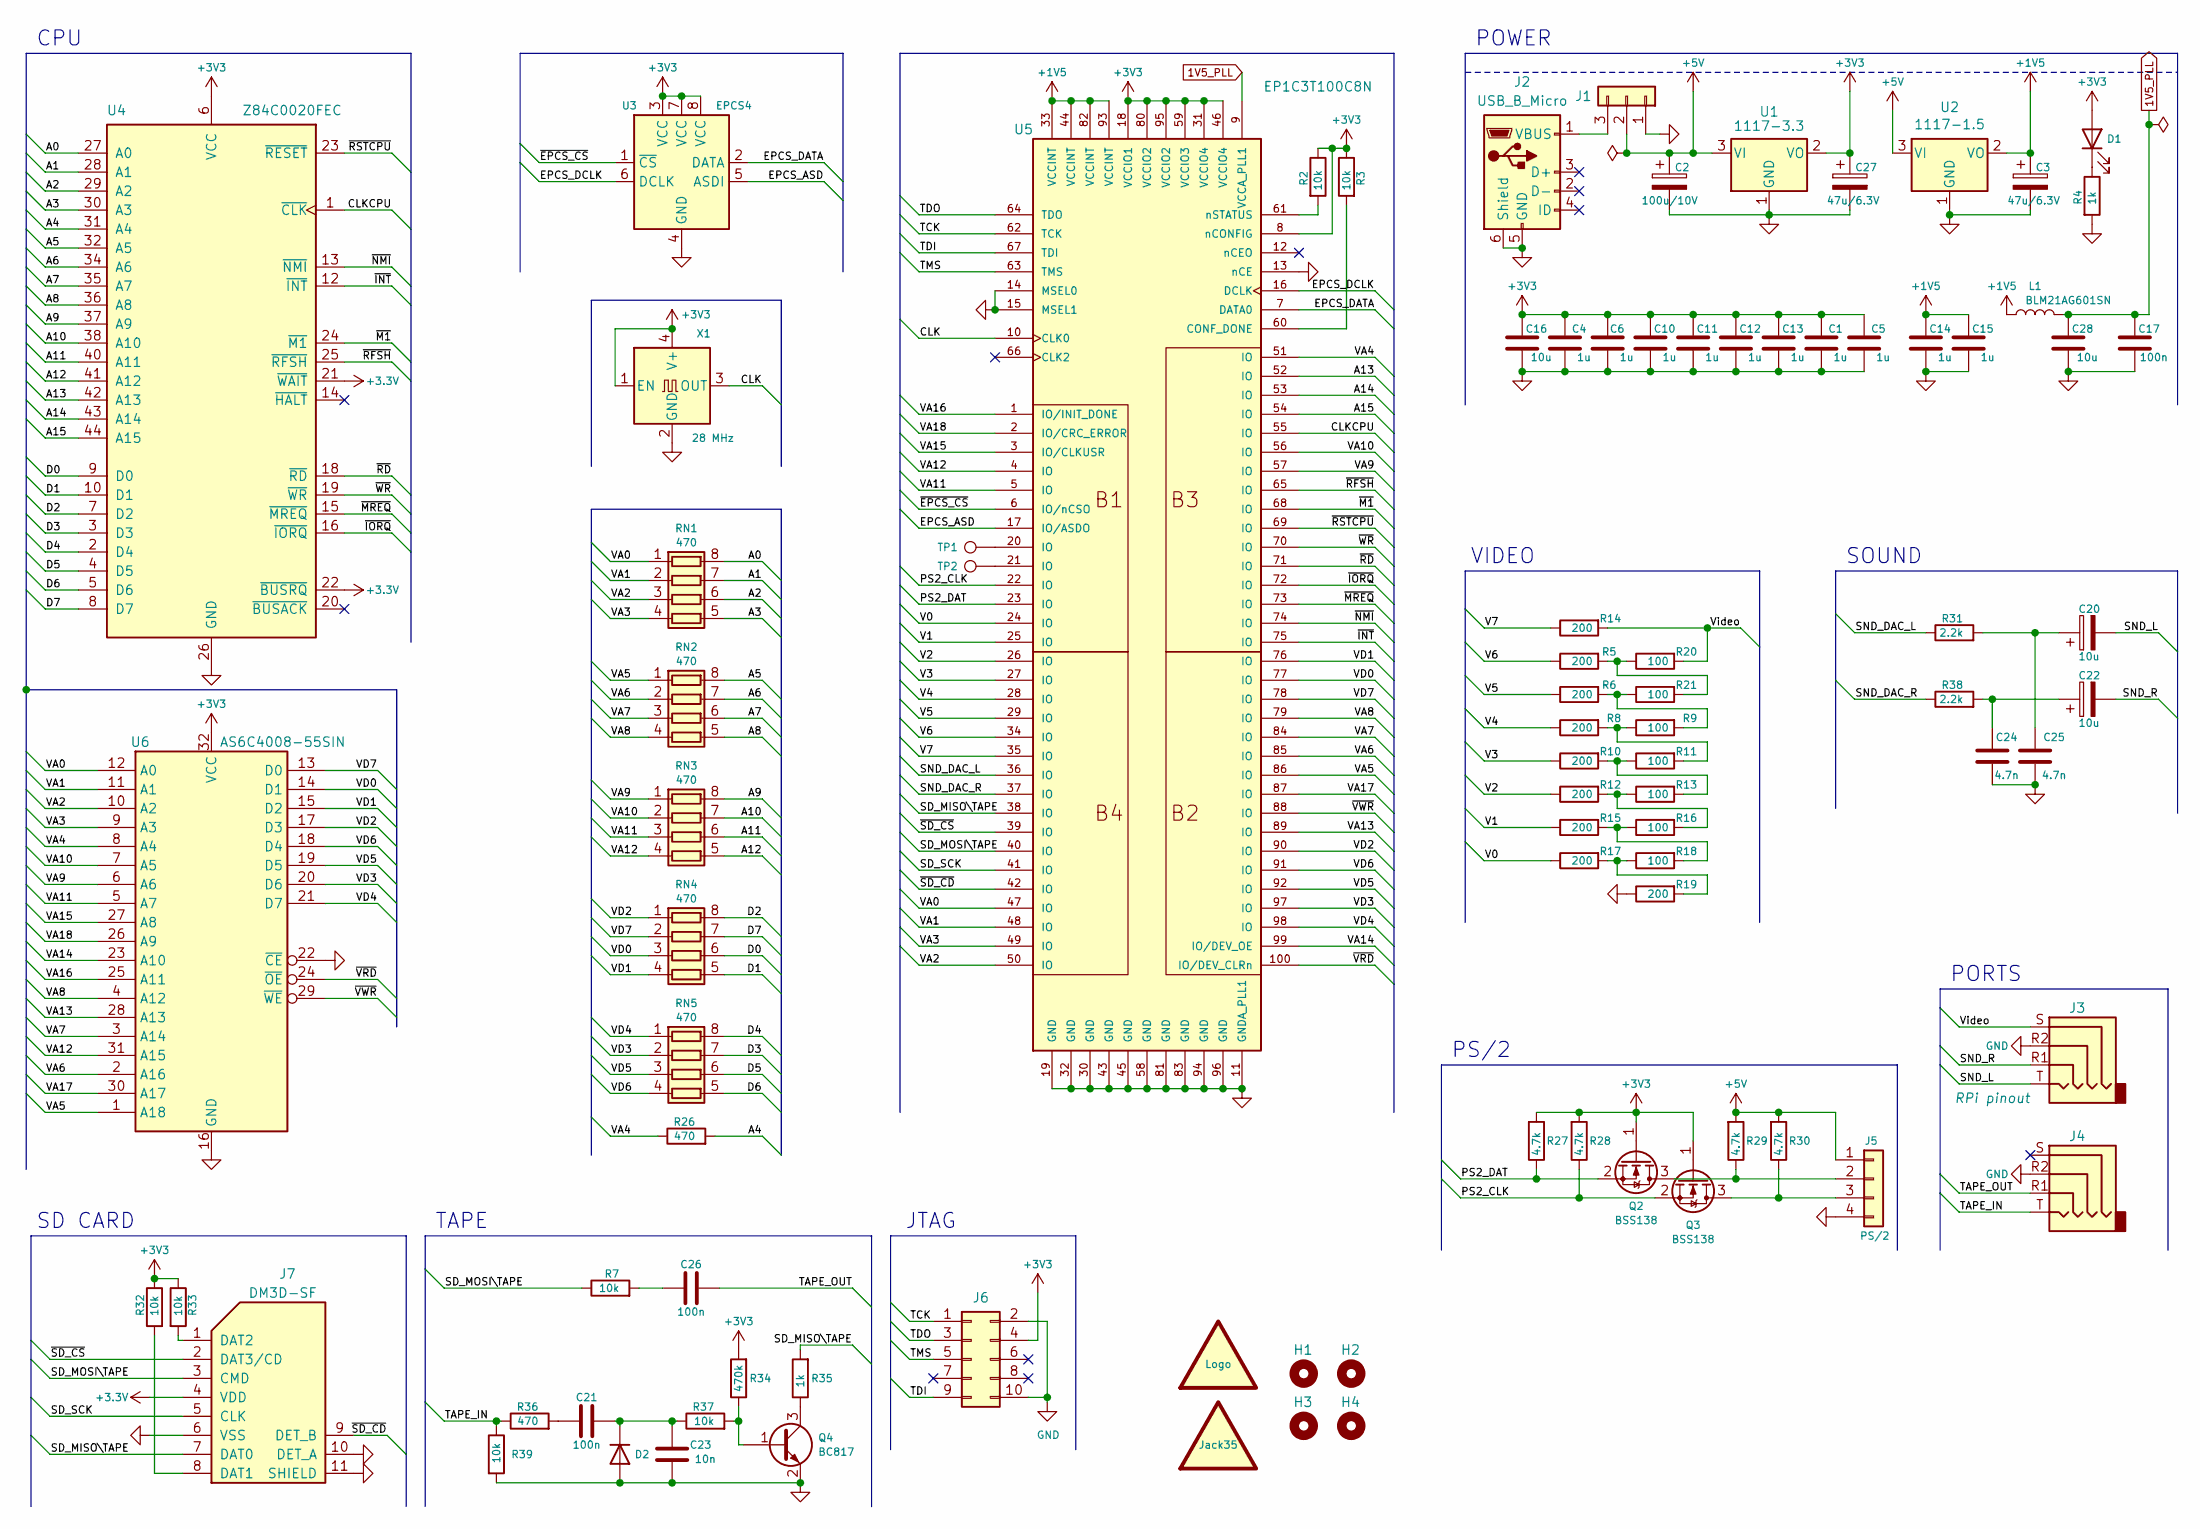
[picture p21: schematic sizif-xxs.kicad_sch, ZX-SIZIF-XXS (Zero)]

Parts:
C1, C4, C5, C6, C10, C11, C12, C13, C14, C15: 1u; C_0603_1608Metric_Pad1.08x0.95mm_HandSolder
C2: 100u/10V; CP_EIA-7343-31_Kemet-D_Pad2.25x2.55mm_HandSolder
C3, C27: 47u/6.3V; CP_EIA-3528-21_Kemet-B_Pad1.50x2.35mm_HandSolder
C16, C28: 10u; C_0805_2012Metric_Pad1.18x1.45mm_HandSolder
C17, C21, C26: 100n; C_0603_1608Metric_Pad1.08x0.95mm_HandSolder
C20, C22: 10u; CP_EIA-3216-18_Kemet-A_Pad1.58x1.35mm_HandSolder
C23: 10n; C_0603_1608Metric_Pad1.08x0.95mm_HandSolder
C24, C25: 4.7n; C_0603_1608Metric_Pad1.08x0.95mm_HandSolder
D1: LED; LED_1210_3225Metric_Pad1.42x2.65mm_HandSolder
D2: 1N4148W; D_SOD-123
H1, H2, H3, H4: MountingHole; MountingHole_2.7mm_M2.5
J1: Pin header 1x3 Pitch=2.54mm; PinHeader_1x03_P2.54mm_Vertical
J2: USB_B_Micro; USB_Micro-B_Molex-105017-0001
J3, J4: PJ-320; Jack_3.5mm_PJ320D_Horizontal
J5: Pin header 1x4 Pitch=2.54mm; PinHeader_1x04_P2.54mm_Vertical
J6: Pin header 2x5 Pitch=2.54mm; PinHeader_2x05_P2.54mm_Vertical
J7: DM3D-SF; microSD_HC_Hirose_DM3D-SF
L1: BLM21AG601SN; L_0805_2012Metric_Pad1.15x1.40mm_HandSolder
LOGO1: graphic; black-mage-9.6x6.5
LOGO2: Jack35; jack35_4pin
Q2, Q3: BSS138; SOT-23
Q4: BC817; SOT-23
R2, R3, R7, R32, R33, R37, R39: 10k; R_0603_1608Metric_Pad0.98x0.95mm_HandSolder
R4, R35: 1k; R_0603_1608Metric_Pad0.98x0.95mm_HandSolder
R5, R6, R8, R10, R12, R14, R15, R17, R19: 200; R_0603_1608Metric_Pad0.98x0.95mm_HandSolder
R9, R11, R13, R16, R18, R20, R21: 100; R_0603_1608Metric_Pad0.98x0.95mm_HandSolder
R26, R36: 470; R_0603_1608Metric_Pad0.98x0.95mm_HandSolder
R27, R28, R29, R30: 4.7k; R_0603_1608Metric_Pad0.98x0.95mm_HandSolder
R31, R38: 2.2k; R_0603_1608Metric_Pad0.98x0.95mm_HandSolder
R34: 470k; R_0603_1608Metric_Pad0.98x0.95mm_HandSolder
RN1, RN2, RN3, RN4, RN5: 470; R_Array_Convex_4x0603
TP1, TP2: TestPoint; TestPoint_Pad_D1.0mm
U1: 1117-3.3; SOT-223-3_TabPin2
U2: 1117-1.5; SOT-223-3_TabPin2
U3: EPCS4; SOIC-8_3.9x4.9mm_P1.27mm
U4: Z84C0020FEC; TQFP-44_14x14mm_P0.8mm
U5: EP1C3T100C8N; TQFP-100_14x14mm_P0.5mm
U6: AS6C4008-55SIN; SSOP-32_11.305x20.495mm_P1.27mm
X1: 28 MHz; Oscillator_SMD_SeikoEpson_SG8002CA-4Pin_7.0x5.0mm

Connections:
1V5_PLL: C17.2, C28.2, L1.2, U5.9 (VCCA_PLL1)
+1V5: C3.1, C14.1, C15.2, L1.1, U2.2 (VO), U5.33 (VCCINT), U5.44 (VCCINT), U5.82 (VCCINT), U5.93 (VCCINT)
+5V: C2.1, J1.2, J5.1, R29.2, R30.2, U1.3 (VI), U2.3 (VI)
/A0: RN1.8 (R1.2), U4.27 (A0)
/A1: RN1.7 (R2.2), U4.28 (A1)
/A2: RN1.6 (R3.2), U4.29 (A2)
/A3: RN1.5 (R4.2), U4.30 (A3)
/A4: R26.2, U4.31 (A4)
/A5: RN2.8 (R1.2), U4.32 (A5)
/A6: RN2.7 (R2.2), U4.34 (A6)
/A7: RN2.6 (R3.2), U4.35 (A7)
/A8: RN2.5 (R4.2), U4.36 (A8)
/A9: RN3.8 (R1.2), U4.37 (A9)
/A10: RN3.7 (R2.2), U4.38 (A10)
/A11: RN3.6 (R3.2), U4.40 (A11)
/A12: RN3.5 (R4.2), U4.41 (A12)
/A13: U4.42 (A13), U5.52 (IO)
/A14: U4.43 (A14), U5.53 (IO)
/A15: U4.44 (A15), U5.54 (IO)
/CLK: U5.10 (CLK0), X1.3 (OUT)
/CLKCPU: U4.1 (~CLK), U5.55 (IO)
/D0: RN4.6 (R3.2), U4.9 (D0)
/D1: RN4.5 (R4.2), U4.10 (D1)
/D2: RN4.8 (R1.2), U4.7 (D2)
/D3: RN5.7 (R2.2), U4.3 (D3)
/D4: RN5.8 (R1.2), U4.2 (D4)
/D5: RN5.6 (R3.2), U4.4 (D5)
/D6: RN5.5 (R4.2), U4.5 (D6)
/D7: RN4.7 (R2.2), U4.8 (D7)
/EPCS_ASD: U3.5 (ASDI), U5.17 (IO/ASDO)
/EPCS_DATA: U3.2 (DATA), U5.7 (DATA0)
/EPCS_DCLK: U3.6 (DCLK), U5.16 (DCLK)
/PS2_CLK: Q3.2 (S), R28.1, U5.22 (IO)
/PS2_DAT: Q2.2 (S), R27.1, U5.23 (IO)
/SD_MISO\TAPE: J7.7 (DAT0), R35.2, U5.38 (IO)
/SD_MOSI\TAPE: J7.3 (CMD), R7.1, U5.40 (IO)
/SD_SCK: J7.5 (CLK), U5.41 (IO)
/SND_DAC_L: R31.1, U5.36 (IO)
/SND_DAC_R: R38.1, U5.37 (IO)
/SND_L: C20.2, J3.T
/SND_R: C22.2, J3.R1
/TAPE_IN: J4.T, R36.1, R39.1
/TAPE_OUT: C26.1, J4.R1
/TCK: J6.1, U5.62 (TCK)
/TDI: J6.9, U5.67 (TDI)
/TDO: J6.3, U5.64 (TDO)
/TMS: J6.5, U5.63 (TMS)
/V0: R17.1, U5.24 (IO)
/V1: R15.1, U5.25 (IO)
/V2: R12.1, U5.26 (IO)
/V3: R10.1, U5.27 (IO)
/V4: R8.1, U5.28 (IO)
/V5: R6.1, U5.29 (IO)
/V6: R5.1, U5.34 (IO)
/V7: R14.1, U5.35 (IO)
/VA0: RN1.1 (R1.1), U5.47 (IO), U6.12 (A0)
/VA1: RN1.2 (R2.1), U5.48 (IO), U6.11 (A1)
/VA2: RN1.3 (R3.1), U5.50 (IO), U6.10 (A2)
/VA3: RN1.4 (R4.1), U5.49 (IO), U6.9 (A3)
/VA4: R26.1, U5.51 (IO), U6.8 (A4)
/VA5: RN2.1 (R1.1), U5.86 (IO), U6.1 (A18)
/VA6: RN2.2 (R2.1), U5.85 (IO), U6.2 (A16)
/VA7: RN2.3 (R3.1), U5.84 (IO), U6.3 (A14)
/VA8: RN2.4 (R4.1), U5.79 (IO), U6.4 (A12)
/VA9: RN3.1 (R1.1), U5.57 (IO), U6.6 (A6)
/VA10: RN3.2 (R2.1), U5.56 (IO), U6.7 (A5)
/VA11: RN3.3 (R3.1), U5.5 (IO), U6.5 (A7)
/VA12: RN3.4 (R4.1), U5.4 (IO), U6.31 (A15)
/VA13: U5.89 (IO), U6.28 (A13)
/VA14: U5.99 (IO/DEV_OE), U6.23 (A10)
/VA15: U5.3 (IO/CLKUSR), U6.27 (A8)
/VA16: U5.1 (IO/INIT_DONE), U6.25 (A11)
/VA17: U5.87 (IO), U6.30 (A17)
/VA18: U5.2 (IO/CRC_ERROR), U6.26 (A9)
/VD0: RN4.3 (R3.1), U5.77 (IO), U6.14 (D1)
/VD1: RN4.4 (R4.1), U5.76 (IO), U6.15 (D2)
/VD2: RN4.1 (R1.1), U5.90 (IO), U6.17 (D3)
/VD3: RN5.2 (R2.1), U5.97 (IO), U6.20 (D6)
/VD4: RN5.1 (R1.1), U5.98 (IO), U6.21 (D7)
/VD5: RN5.3 (R3.1), U5.92 (IO), U6.19 (D5)
/VD6: RN5.4 (R4.1), U5.91 (IO), U6.18 (D4)
/VD7: RN4.2 (R2.1), U5.78 (IO), U6.13 (D0)
/Video: J3.S, R14.2, R20.2
/~EPCS_CS: U3.1 (~CS), U5.6 (IO/nCSO)
/~INT: U4.12 (~INT), U5.75 (IO)
/~IORQ: U4.16 (~IORQ), U5.72 (IO)
/~M1: U4.24 (~M1), U5.68 (IO)
/~MREQ: U4.15 (~MREQ), U5.73 (IO)
/~NMI: U4.13 (~NMI), U5.74 (IO)
/~RD: U4.18 (~RD), U5.71 (IO)
/~RFSH: U4.25 (~RFSH), U5.65 (IO)
/~RSTCPU: U4.23 (~RESET), U5.69 (IO)
/~SD_CD: J7.9 (DET_B), U5.42 (IO)
/~SD_CS: J7.2 (DAT3/CD), U5.39 (IO)
/~VRD: U5.100 (IO/DEV_CLRn), U6.24 (~OE)
/~VWR: U5.88 (IO), U6.29 (~WE)
/~WR: U4.19 (~WR), U5.70 (IO)
GND: C1.2, C2.2, C3.2, C4.1, C5.2, C6.2, C10.2, C11.2, C12.2, C13.2, C14.2, C15.1, C16.1, C17.1, C23.2, C24.2, C25.2, C27.2, C28.1, D2.2 (A), J1.1, J2.5 (GND), J2.6 (Shield), J3.R2, J4.R2, J5.4, J6.2, J6.10, J7.6 (VSS), J7.10 (DET_A), J7.11 (SHIELD), Q4.2 (E), R4.2, R19.1, R39.2, U1.1 (GND), U2.1 (GND), U3.4 (GND), U4.26 (GND), U5.11 (GNDA_PLL1), U5.13 (nCE), U5.14 (MSEL0), U5.15 (MSEL1), U5.19 (GND), U5.30 (GND), U5.32 (GND), U5.43 (GND), U5.45 (GND), U5.58 (GND), U5.81 (GND), U5.83 (GND), U5.94 (GND), U5.96 (GND), U6.16 (GND), U6.22 (~CE), X1.2 (GND)
unnamed: C20.1, C25.1, R31.2
unnamed: C21.1, C23.1, D2.1 (K), R37.1
unnamed: C21.2, R36.2
unnamed: C22.1, C24.1, R38.2
unnamed: C26.2, R7.2
unnamed: D1.1 (K), R4.1
unnamed: J1.3, J2.1 (VBUS)
unnamed: J5.2, Q2.3 (D), R29.1
unnamed: J5.3, Q3.3 (D), R30.1
unnamed: J7.1 (DAT2), R33.2
unnamed: J7.8 (DAT1), R32.2
unnamed: Q4.1 (B), R34.1, R37.2
unnamed: Q4.3 (C), R35.1
unnamed: R2.2, U5.61 (nSTATUS)
unnamed: R3.2, U5.60 (CONF_DONE)
unnamed: R10.2, R11.1, R13.2
unnamed: R8.2, R9.1, R11.2
unnamed: R12.2, R13.1, R16.2
unnamed: R15.2, R16.1, R18.2
unnamed: R17.2, R18.1, R19.2
unnamed: R5.2, R20.1, R21.2
unnamed: R6.2, R9.2, R21.1
unnamed: TP1.1, U5.20 (IO)
unnamed: TP2.1, U5.21 (IO)

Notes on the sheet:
PS/2
TAPE
PORTS
JTAG
SD CARD
SOUND
POWER
CPU
VIDEO

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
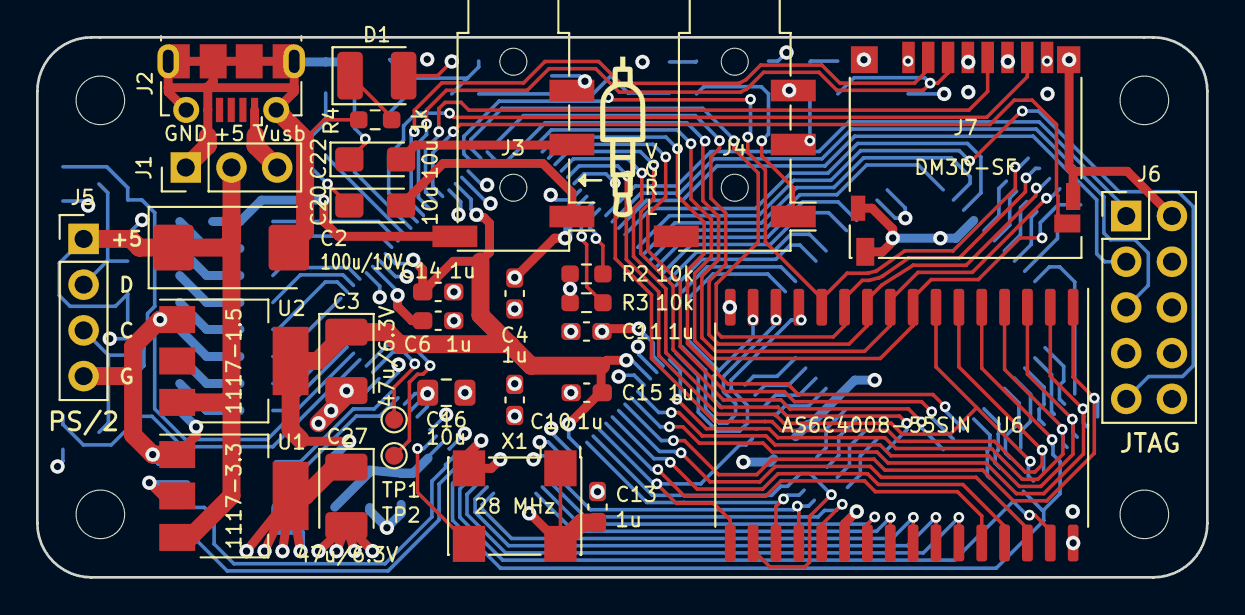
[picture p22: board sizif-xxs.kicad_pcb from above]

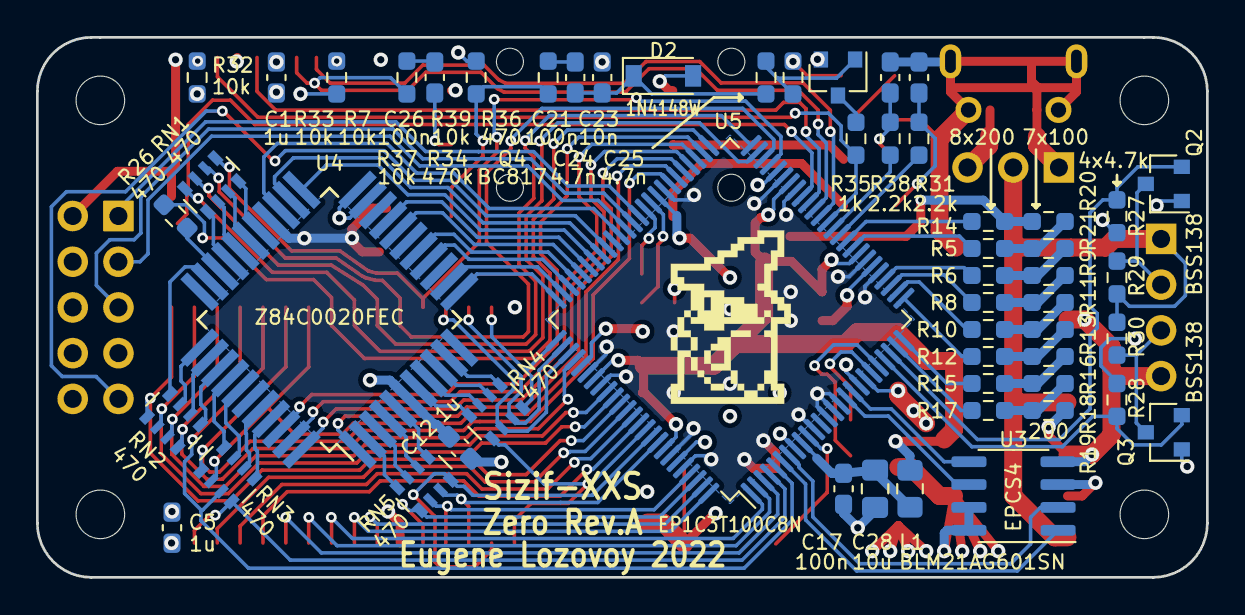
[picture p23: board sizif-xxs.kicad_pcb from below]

Board: 4 copper layers, 65.0 x 30.0 mm, 90 parts (55 on the bottom side), 123 nets.

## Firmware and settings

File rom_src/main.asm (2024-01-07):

    ASSERT __SJASMPLUS__ >= 0x011402 ; SjASMPlus 1.20.2
    OPT --syntax=abf
    DEVICE ZXSPECTRUM48

; Startup handler
    ORG #0000
    ex de, hl ; EB opcode used by CPLD to determine magic ROM presence
    ex de, hl ; ...
    jp startup_handler
    DB 0,"Sizif Magic ROM",0

; NMI handler
    ORG #0066
    ex de, hl ; EB opcode used by CPLD to determine magic ROM presence
    ex de, hl ; ...
    jp nmi_handler

; INT IM1 handler
    ORG #0038
    push bc
    ld bc, #0038
    ld (var_int_vector), bc
    pop bc
    ret

; INT IM2 handler
    ORG #0101
    ret

; INT IM2 vector table
    ORG #0200
    .257 db #01 ; by Z80 user manual int vector is I * 256 + (D & 0xFE)
                ; but by other references and by T80/A-Z80 implementation int vector is I * 256 + D
                ; so we just play safe and use symmetric int handler address and vector table with one extra byte


    ORG #0570   ; this address chosen to do not overlap with divmmc entrypoints
startup_handler:
    ld sp, Stack_top
    ld ix, #5800    ; draw 4 rygb boxes on left top corner to indicate boot
    ld (ix+0), #D2  ; r
    ld (ix+1), #F6  ; y
    call check_initialized
    jr z, .warm_boot
    im 1            ; wait for ps/2 keyboard ready
    ld b, POWERON_DELAY ; ...
.loop               ; ...
    ei              ; ...
    halt            ; ...
    djnz .loop      ; ...
    call init_default_config
    call detect_sd_card
.warm_boot:
    call load_config
    call init_cpld
    call save_initialized
    ld ix, #5800    ; draw 4 rygb boxes on left top corner to indicate boot
    ld (ix+2), #E4  ; g
    ld (ix+3), #C9  ; b
    ld hl, 0
    jp exit_with_jp


nmi_handler:
    ld (var_sp_reg), sp
    ld sp, Stack_top
    push af
    push hl
    push bc
    ld a, 1                   ; show magic border
    ld bc, #01ff              ; ...
    out (c), a                ; ...
    xor a
    ld (var_magic_enter_cnt), a
    ld (var_magic_leave_cnt), a
.key_wait_loop:
    call check_entering_pause ; A[1] == 1 if pause button is pressed
    bit 1, a                  ; ...
    jp nz, .enter_pause       ; ...
    call delay_10ms           ;
    call check_entering_menu  ; A == 1 if we are entering menu, A == 2 if we are leaving to...
    bit 0, a                  ; ...default nmi handler, A == 0 otherwise
    jp nz, .enter_menu        ; ...
    bit 1, a                  ; ...
    jr z, .key_wait_loop      ; ...
.leave_no_key:
    xor a                     ; disable border
    ld bc, #01ff              ; ...
    out (c), a                ; ...
    ld bc, #00ff              ; ...
    in a, (c)                 ; if divmmc paged - just do retn
    bit 3, a                  ; ...
    jr nz, exit_with_ret      ; ...
    ld hl, #0066              ; otherwise jump to default nmi handler
    jr exit_with_jp           ; ...

.enter_pause:
    ld hl, nmi_pause
    ld (var_main_fun), hl
    jr .enter
.enter_menu:
    ld hl, nmi_menu
    ld (var_main_fun), hl
    ;jr .enter
.enter:
    push de
    push ix
    push iy
    ld a, i                   ; save I reg and IFF2
    push af                   ; ...
    ld a, #02                 ; set our IM2 interrupt table address (#02xx)
    ld i, a                   ; ...
    xor a
    ld (var_exit_flag), a
    ld (var_exit_reboot), a
    call input_init
    call save
.run_fun:
    ld hl, .leave             ; place ret address to stack
    push hl                   ; ...
    ld hl, (var_main_fun)     ; jump to our loop function
    jp (hl)                   ; ...
.leave:
    call save_config
    call restore
    ld a, (var_exit_reboot)   ; should we reboot?
    or a                      ; ...
    jr z, .leave_without_reboot ; ...
    ld a, 2                   ; reboot
    ld bc, #01ff              ; ...
    out (c), a                ; ...
.leave_without_reboot:
    pop af                    ; A = I
    push af                   ;
    call get_im2_handler      ; HL = default im2 handler address
    ld (var_int_vector), hl
    xor a                     ; disable border
    ld bc, #01ff              ; ...
    out (c), a                ; ...
    pop af
    pop iy
    pop ix
    pop de
    ei                        ; wait for int just for safety
    halt                      ; ...
    ld i, a                   ; restore default interrupt table address
    jp po, exit_with_ret      ; check int was enabled by default. no? just do retn
    ld hl, (var_int_vector)   ; ...
    jp exit_with_jp           ; yes? goto default int handler


; IN  - HL - jump address
exit_with_jp:
    ld (Exit_vector-1), hl
    ld a, #c3                ; c3 - jp
    ld (Exit_vector-2), a
    pop bc
    pop hl
    pop af
    ld sp, (var_sp_reg)
    jp Exit_vector-2

exit_with_ret:
    ld hl, #45ed             ; ed45 - retn; reverse bytes order
    ld (Exit_vector-1), hl
    pop bc
    pop hl
    pop af
    ld sp, (var_sp_reg)
    jp Exit_vector-1


check_initialized:
    ld hl, cfg_initialized     ; if (cfg_initialized == "magic word") Z = 0, else Z = 1
.check:
    ld a, #B1                  ; ...
    cpi                        ; ... hl++
    ret nz                     ; ...
    ld a, #5B                  ; ...
    cpi                        ; ... hl++
    ret nz                     ; ...
    ld a, #00                  ; ...
    cpi                        ; ... hl++
    ret nz                     ; ...
    ld a, #B5                  ; ...
    cpi                        ; ... hl++
    ret

save_initialized:
    ld hl, #5BB1               ; cfg_initialized = "magic word"
    ld (cfg_initialized+0), hl ; ...
    ld hl, #B500               ; ...
    ld (cfg_initialized+2), hl ; ...
    ret

init_default_config:
    ld bc, CFG_T          ; cfg_saved = cfg_default
    ld de, cfg_saved      ; ...
    ld hl, CFG_DEFAULT    ; ...
    ldir                  ; ...

load_config:
    ld bc, CFG_T          ; cfg = cfg_saved
    ld de, cfg            ; ...
    ld hl, cfg_saved      ; ...
    ldir                  ; ...
    ret                   ; ...

save_config:
    ld bc, CFG_T          ; cfg_saved = cfg
    ld de, cfg_saved      ; ...
    ld hl, cfg            ; ...
    ldir                  ; ...
    ret


init_cpld:
.check_7ffd_disabled:
    ld a, (cfg.machine)         ; if machine == 48 - set 7ffd rom to basic48
    or a                        ; ... this is required for case when machine will be
    jr nz, .check_1ffd_disabled ; ... changed later by magic menu - this prevents
    ld a, #10                   ; ... hang if user changes machine while basic48 active
    ld bc, #7ffd                ; ...
    out (c), a                  ; ...
.check_1ffd_disabled:
    ld a, (cfg.machine)         ; if machine != +3 - set 1ffd rom to basic48
    cp 2                        ; ... this is required for case when +3 will be
    jr z, .do_load              ; ... activated later by magic menu - this prevents
    ld a, #4                    ; ... hang if user activate +3 while basic48 active
    ld bc, #1ffd                ; ...
    out (c), a                  ; ...
.do_load:
    ld b, CFG_T        ; B = registers count
    ld c, #ff          ;
    ld hl, cfg+CFG_T-1 ; HL = &cfg[registers count-1]
    otdr               ; do { b--; out(bc, *hl); hl--; } while(b)
    ret


detect_sd_card:
    in a, (#77)                 ; read sd_cd state from ZC status port
    bit 0, a                    ; check sd_cd == 0 (card is insert)
    jr z, .is_insert            ; yes?
.no_card:
    xor a                       ; sd = OFF
    ld (cfg_saved.sd), a        ; ...
    ret
.is_insert:
    ld a, 1                     ; sd = divmmc
    ld (cfg_saved.sd), a        ; ...
    ret


; OUT - A bit 1 if we are entering pause, 0 otherwise
check_entering_pause:
    xor a                       ; read pause key state in bit 1 of #00FF port
    in a, (#ff)                 ; ...
    ret


; OUT -  A = 1 if we are entering menu, A = 2 if we are leaving menu, A = 0 otherwise
; OUT -  F - garbage
check_entering_menu:
    xor a                       ; read magic key state in bit 0 of #00FF port
    in a, (#ff)                 ; ...
    bit 0, a                    ; check key is hold
    jr nz, .is_hold             ; yes?
.not_hold:
    ld a, (var_magic_leave_cnt) ; leave_counter++
    inc a                       ; ...
    ld (var_magic_leave_cnt), a ; ...
    cp MENU_LEAVE_DELAY         ; if (counter == MENU_LEAVE_DELAY) - return 2
    jr nz, .return0             ; ...
    ld a, 2
    ret
.is_hold:
    ld a, (var_magic_enter_cnt) ; enter_counter++
    inc a                       ; ...
    ld (var_magic_enter_cnt), a ; ...
    cp MENU_ENTER_DELAY         ; if (counter == MENU_ENTER_DELAY) - return 1
    jr nz, .return0             ; ...
    ld a, 1
    ret
.return0:
    xor a
    ret


; OUT - AF - garbage
; OUT - BC - garbage
delay_10ms:
    ld c, 7
    ld a, (cfg.clock)
    or a
    jr z, .loop
    ld c, 9
    dec a
    jr z, .loop
    ld c, 11
    dec a
    jr z, .loop
    ld c, 7*2
    dec a
    jr z, .loop
    ld c, 7*4
.loop:
    ld a, c
.loop_outer:
    ld b, 255                 ; ~1ms cycle at 3.5MHz
.loop_inner:                  ; ...
    djnz .loop_inner          ; 13 T-states
    dec a
    jr nz, .loop_outer
    ret


; read non-magic im2 table and returns im2 handler address
; IN  -  A - im2 table address hight byte
; OUT - HL - handler address
; OUT - AF - garbage
get_im2_handler:
    ld h, a                   ; HL = im2 table address
    ld l, #ff                 ; HL = im2 table address
    ld a, #2a                 ; 2a - ld hl, (nn)
    ld (Readout_vector-2), a  ; ...
    ld (Readout_vector-1), hl ; HL was set earlier by im2 table address
    ld a, #c9                 ; c9 - ret
    ld (Readout_vector+1), a  ; ...
    call Readout_vector-2     ; HL = default im2 handler address
    ret


save:
.save_ay:
    ld hl, var_save_ay ; select first AY chip in TurboSound
    ld a, #ff          ; ...
    call .save_ay_sub
    ld a, #fe          ; select second AY chip in TurboSound
    call .save_ay_sub
.save_screen:
    ld bc, 6912
    ld de, var_save_screen
    ld hl, #4000
    ldir
.save_ulaplus:
    ld bc, #bf3b       ; set ulaplus address = mode register
    ld a, #40          ; ...
    out (c), a         ; ...
    ld bc, #ff3b       ; save mode register value
    in a, (c)          ; ...
    bit 7, a             ; if bit 7 != 0 - assume no ulaplus there
    jr z, .save_ulaplus1 ; ... so save 0 (disabled) state
    xor a                ; ... for case when user will enable ulaplus in menu later
.save_ulaplus1:
    ld (var_save_ulaplus), a ; ...
    xor a              ; disable ulaplus
    out (c), a         ; ...
    ret

.save_ay_sub:
    ld bc, #fffd       ; ...
    out (c), a         ; ...
    ld d, 16           ; register_number=16
.save_ay_sub_loop:
    dec d              ; register_number--
    ld b, #ff          ; select register number
    out (c), d         ; ...
    in a, (c)          ; read register
    ld (hl), a         ; save to ram
    xor a              ; set register to 0
    ld b, #bf          ; ...
    out (c), a         ; ...
    inc hl             ; ram++
    or d               ; register_number == 0?
    jr nz, .save_ay_sub_loop
    ret


restore:
.restore_ulaplus:
    ld bc, #bf3b       ; set ulaplus address = mode register
    ld a, #40          ; ...
    out (c), a         ; ...
    ld bc, #ff3b       ; restore mode register value
    ld a, (var_save_ulaplus) ; ...
    out (c), a         ; ...
.restore_screen:
    call restore_screen
.restore_ay:
    ld hl, var_save_ay+16 ; select second AY chip in TurboSound
    ld a, #fe             ; ...
    call .restore_ay_sub
    ld hl, var_save_ay    ; select first AY chip in TurboSound
    ld a, #ff             ; ...
    call .restore_ay_sub
.restore_ret:
    ret

.restore_ay_sub:
    ld bc, #fffd       ; ...
    out (c), a         ; ...
    ld d, 16           ; register_number=16
.restore_ay_sub_loop:
    dec d              ; register_number--
    ld b, #ff          ; select register number
    out (c), d         ; ...
    ld b, #bf          ; restore register
    ld a, (hl)         ; ...
    out (c), a         ; ...
    inc hl             ; ram++
    xor a              ; register_number == 0?
    or d               ; ...
    jr nz, .restore_ay_sub_loop ;
    ret

restore_screen:
    ld bc, 6912
    ld de, #4000
    ld hl, var_save_screen
    ldir
    ret


nmi_pause:
    xor a
    ld (var_exit_flag), a
    call pause_init
.loop:
    ei
    halt
    call pause_process
    ld a, (var_exit_flag)
    or a
    jr z, .loop
.wait_for_pause_key_release:
    xor a              ; read magic/pause keys state from port #00FF
    in a, (#ff)        ; ...
    and #03            ; ...
    jr nz, .wait_for_pause_key_release
    ret


nmi_menu:
    call check_initialized
    jr z, .init1
    call init_default_config
    call load_config
    call save_initialized
.init1:
    ld hl, menudefault
    ld (var_menumain), hl
    call menu_init
.loop:
    call menu_input_loop
    call wait_for_keys_release
    ret


menu_input_loop:
    xor a
    ld (var_exit_flag), a
    ld (var_exit_reboot), a
.loop:
    ei
    halt
    call input_process ; B = 32 if exit key pressed
    bit 5, b
    ret nz
    call menu_process
    ld a, (var_exit_flag)
    or a
    jr z, .loop
    ret


wait_for_keys_release:
.loop:
    ei
    halt
    call input_process ; B = 0 if no keys pressed
    xor a
    or b
    jr nz, .loop
    xor a              ; read magic/pause keys state from port #00FF
    in a, (#ff)        ; ...
    and #03            ; ...
    jr nz, .loop
    ret


; Includes
    include config.asm
    include draw.asm
    include input.asm
    include pause.asm
    include menu.asm
    include menu_structure.asm
    include font.asm
    include strings.asm

    DISPLAY "Free space: ",/D,fwinfo-$," (",$,")"
    ASSERT $ < fwinfo


; Just some firmware info at the end of ROM
    ORG #2000-(fwinfo.end-fwinfo)
fwinfo:
    DB 0
.version:
    DB VERSION, 0
.date
    DB __DATE__, 0
.time:
    DB __TIME__, 0
    DB "End of Sizif Magic ROM", 0
.end

; Variables
    ORG #C000
    include variables.asm
var_ram_func:
    .256 DB 0
    ASSERT $ < #EFF0

; Magic vectors
    ORG #F000
Exit_vector:
    ORG #F008
Readout_vector:

    ORG #FFBE
Stack_top:
    ORG #FFC0
Ulaplus_pallete:
    .64 DB 0


    CSPECTMAP "main.map"
    SAVEBIN "main.bin",0,8192

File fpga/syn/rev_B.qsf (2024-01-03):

# -------------------------------------------------------------------------- #
#
# Copyright (C) 1991-2009 Altera Corporation
# Your use of Altera Corporation's design tools, logic functions
# and other software and tools, and its AMPP partner logic
# functions, and any output files from any of the foregoing
# (including device programming or simulation files), and any
# associated documentation or information are expressly subject
# to the terms and conditions of the Altera Program License
# Subscription Agreement, Altera MegaCore Function License
# Agreement, or other applicable license agreement, including,
# without limitation, that your use is for the sole purpose of
# programming logic devices manufactured by Altera and sold by
# Altera or its authorized distributors.  Please refer to the
# applicable agreement for further details.
#
# -------------------------------------------------------------------------- #
#
# Quartus II
# Version 9.0 Build 235 06/17/2009 Service Pack 2 SJ Web Edition
# Date created = 08:15:12  April 28, 2019
#
# -------------------------------------------------------------------------- #
#
# Notes:
#
# 1) The default values for assignments are stored in the file:
#		rev_B_assignment_defaults.qdf
#    If this file doesn't exist, see file:
#		assignment_defaults.qdf
#
# 2) Altera recommends that you do not modify this file. This
#    file is updated automatically by the Quartus II software
#    and any changes you make may be lost or overwritten.
#
# -------------------------------------------------------------------------- #


set_global_assignment -name FAMILY Cyclone
set_global_assignment -name DEVICE EP1C3T100C8
set_global_assignment -name TOP_LEVEL_ENTITY zx_ula
set_global_assignment -name ORIGINAL_QUARTUS_VERSION "13.0 SP1"
set_global_assignment -name PROJECT_CREATION_TIME_DATE "19:57:09  NOVEMBER 08, 2021"
set_global_assignment -name LAST_QUARTUS_VERSION "13.0 SP1"
set_global_assignment -name USE_GENERATED_PHYSICAL_CONSTRAINTS OFF -section_id eda_blast_fpga
set_global_assignment -name MAX7000_DEVICE_IO_STANDARD "3.3-V LVTTL"
set_global_assignment -name VERILOG_INPUT_VERSION SYSTEMVERILOG_2005
set_global_assignment -name VERILOG_SHOW_LMF_MAPPING_MESSAGES OFF
set_global_assignment -name MAX7000_OPTIMIZATION_TECHNIQUE AREA
set_global_assignment -name FMAX_REQUIREMENT "14.4 MHz"
set_global_assignment -name FMAX_REQUIREMENT "14.4 MHz" -section_id clk14
set_global_assignment -name FMAX_REQUIREMENT "7.156 MHz" -section_id clkcpu
set_instance_assignment -name CLOCK_SETTINGS clkcpu -to clkcpu
set_global_assignment -name AUTO_LCELL_INSERTION OFF
set_global_assignment -name FMAX_REQUIREMENT "32 MHz" -section_id clk32
set_global_assignment -name FMAX_REQUIREMENT "8 MHz" -section_id clk8
set_global_assignment -name FMAX_REQUIREMENT "4 MHz" -section_id clk4
set_instance_assignment -name CLOCK_SETTINGS clk8 -to "lpm_counter:wgcnt_rtl_1|dffs[1]"
set_instance_assignment -name CLOCK_SETTINGS clk4 -to "lpm_counter:wgcnt_rtl_1|dffs[2]"

set_global_assignment -name OPTIMIZE_HOLD_TIMING "ALL PATHS"
set_global_assignment -name FITTER_EFFORT "STANDARD FIT"
set_global_assignment -name PROJECT_OUTPUT_DIRECTORY output/
set_global_assignment -name FMAX_REQUIREMENT "7.156 MHz" -section_id clk7
set_global_assignment -name DUTY_CYCLE 40 -section_id clk7

set_global_assignment -name SAVE_DISK_SPACE OFF
set_global_assignment -name SMART_RECOMPILE ON
set_global_assignment -name POWER_USE_PVA OFF
set_global_assignment -name OPTIMIZE_MULTI_CORNER_TIMING ON
set_global_assignment -name SYNTH_TIMING_DRIVEN_SYNTHESIS OFF
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

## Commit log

2021-05-02 add pcb rev.A
    [sizif-xxs.kicad_pcb, sizif-xxs.sch]
2021-05-04 ps2: handle more buttons, add kempston
2021-05-06 fix switching to turbo 14MHz mode
2021-05-06 significant stability improvements with 48K/128K timings
    [divmmc.sv, ports.sv]
2021-05-26 add errata for pcb rev.A
2021-06-19 magic rom: fix ay restore when there is no turbosound
    [main.asm]
2021-06-30 magic: fix border when entering menu
    [main.asm]
2021-06-30 magic rom: fix hot switching to +3 mode when basic48 active
    [main.asm]
2021-06-30 magic rom: fix possible crash on start
    [main.asm]
2021-07-01 add tape output on sd_mosi pin
2021-09-21 merge latest changes from sizif-512
    * add 4.4 MHz and 5.2 MHz turbo modes
    * handle magic key press if initialization wasn't completed before
    * replace 'timings', 'ram', 'plus3' settings with one 'machine' setting
    * refactor memory controller
    * significantly improve classic timings
    * magic rom: fix 'h' font character
    * fix hanging of esxdos browser after magic key double press
    * enable divmmc (esxdos OS) by magic rom on poweron; add NO-OS option
    * improve pause ('f12' on ps/2 keyboard or 'start' on gamepad)
    * magic rom: handle C-key on sega gamepad as exit
    [divmmc.sv, main.asm]
2021-10-26 update pcb rev.A errata
2021-11-14 fix incorrect pallete after enabling ulaplus in menu
    [main.asm]
2021-11-14 mixer: don't switch ABC-ACB panning for second ay in turbosound
    turbosound assume only ABC panning
2021-11-15 replace composite video output implementation
    New one is borrowed from Speccy 2010 project. It's have a much, much
    better output quality in price of increased FPGA resources usage.
    [sizif-xxs.sch]
2022-02-01 fix #1ffd port decoding
    [ports.sv]
2022-02-01 add support for ZC SD card controller; replace NO-OS divmmc mode with ZC
    [divmmc.sv, main.asm]
2022-02-19 add pcb rev.B
    [sizif-xxs.kicad_pcb, sizif-xxs.kicad_sch]
2022-02-19 add pcb rev.B gerbers, pdf, etc...
2022-03-10 add pcb rev.A pdf and interactive bom
2022-06-26 fix kempston port decoding - add DF port for some rare games
    [ports.sv]
2022-07-01 add pcb zero rev.A
    [sizif-xxs.kicad_pcb, sizif-xxs.kicad_sch]
2022-07-01 add pcb zero rev.A gerbers, pdf, etc...
2024-01-08 refactor memory controller
    Also this commit fixes ula+ io contention for classic timings. This
    affects ham256.tap.
    [divmmc.sv]
2024-01-10 fix basic 128 crashes when divmmc is enabled
    [divmmc.sv]
